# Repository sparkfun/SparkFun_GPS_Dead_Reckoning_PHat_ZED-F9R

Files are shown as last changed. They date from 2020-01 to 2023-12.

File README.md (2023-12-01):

SparkFun GPS-RTK Dead Reckoning pHAT (ZED-F9R) for Raspberry Pi
========================================

SparkFun GPS-RTK Dead Reckoning pHAT (ZED-F9R) for Raspberry Pi (https://www.sparkfun.com/products/21305)

[*SparkFun GPS-RTK Dead Reckoning pHAT (ZED-F9R) for Raspberry Pi (GPS-21305)*](https://www.sparkfun.com/products/21305)

The SparkFun ZED-F9R GPS pHAT is a high precision, sensor fusion GPS board with equally impressive configuration options and takes advantage of u-blox's Automotive Dead Reckoning (ADR) technology. The ZED-F9R module provides a highly accurate and continuous position by fusing a 3D IMU sensor, wheel ticks, a vehicle dynamics model, correction data, and GNSS measurements.

The ZED-F9R module is an 184-channel u-blox F9 engine GNSS receiver, meaning it can receive signals from the GPS, GLONASS, Galileo, and BeiDou constellations with ~0.01-meter accuracy! That's right, such accuracy can be achieved with an RTK navigation solution when used with a correction source. Note that the ZED-F9R can only operate as a rover, so you will need to connect to a base station. The module supports the concurrent reception of four GNSS systems. The combination of GNSS and integrated 3D sensor measurements on the ZED-F9R provides accurate, real-time positioning rates of up to 30Hz.

This pHAT maximizes position accuracy in dense cities or covered areas compared to other GPS modules. Even under poor signal conditions, continuous positioning is provided in urban environments and available during complete signal loss (e.g., short tunnels and parking garages). The ZED-F9R is the ultimate solution for autonomous robotic applications that require accurate positioning under challenging conditions.

This u-blox receiver supports a few serial protocols. By default, we used the Raspberry Pi's serial UART to communicate with the module. With pre-soldered headers, no soldering is required to stack the pHAT on a Raspberry Pi, NVIDIA Jetson Nano, Google Coral, or any single-board computer with the 2x20 form factor. We have also broken out a few 0.1"-spaced pins from the u-blox receiver. A Qwiic connector is also added if you need to connect a Qwiic-enabled device.

U-blox-based GPS products are configurable using the popular but dense Windows program u-center. Many different functions can be configured on the ZED-F9R: baud rates, update rates, geofencing, spoofing detection, external interrupts, SBAS/D-GPS, etc.

The SparkFun ZED-F9R GPS pHAT also has an onboard rechargeable battery that provides power to the RTC on the ZED-F9R. This reduces the time-to-first fix from a cold start (~24s) to a hot start (~2s). The battery will maintain RTC and GNSS orbit data without being connected to power for plenty of time.

Repository Contents
-------------------

* **/Documentation** - Data sheets, additional product information
* **/Hardware** - Eagle design files (.brd, .sch)
* **/Production** - Production panel files (.brd)

Documentation
--------------
* **[Library](https://github.com/sparkfun/Qwiic_Ublox_Gps_Py)** - Python library for the ZED-F9R.
* **[Hookup Guide](https://learn.sparkfun.com/tutorials/1172)** - Basic hookup guide for the ZED-F9R.

Product Versions
----------------
* [GPS-21305](https://www.sparkfun.com/products/21305)
* [GPS-16475](https://www.sparkfun.com/products/16475)

Version History
---------------
* [v1.1](https://github.com/sparkfun/SparkFun_GPS_Dead_Reckoning_PHat_ZED-F9R/releases/tag/v1.1)
* [v1.0](https://github.com/sparkfun/SparkFun_GPS_Dead_Reckoning_PHat_ZED-F9R/releases/tag/v1.0) - Initial Release

License Information
-------------------

This product is _**open source**_! 

Please review the LICENSE.md file for license information. 

If you have any questions or concerns on licensing, please contact technical support on our [SparkFun forums](https://forum.sparkfun.com/viewforum.php?f=152).

Distributed as-is; no warranty is given.

- Your friends at SparkFun.

_<COLLABORATION CREDIT>_

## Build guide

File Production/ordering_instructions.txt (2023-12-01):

panel size, 145x137mm
PCB thickness, 1.6mm
number of layers, 2
soldermask color, Red
silkscreen color, White
oz copper, 1oz
finish, HASL lead free
stencils, top
pcs per panel, 4
min trace width, 0.2032mm / 0.0080in
min drill size, 0.3048mm / 0.0120in

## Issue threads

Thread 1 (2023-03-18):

Where can I find the pinout?

clahil-linum, 2023-03-18:
### Subject of the issue

I try to figure out which pins of the ZED-F9R are connected to which pins of the Raspberry pHAT? I searched the Wiki, try to find something with Google but nothing comes up. I'm especially interessted in the geofence pin.

The only information I found is that the pHat uses the UART from this video: https://www.youtube.com/watch?v=ITBoPNNsycY

bboyho, 2023-12-01:
Hi!

I just noticed this question when updating the GitHub repo. The YouTube video is just the SparkFun product showcase.

For more information, you will want to check the product page or [tutorial](https://learn.sparkfun.com/tutorials/sparkfun-gps-rtk-dead-reckoning-zed-f9r-hookup-guide/hardware-overview-phat). The [pHAT's Eagle design files](https://learn.sparkfun.com/tutorials/sparkfun-gps-rtk-dead-reckoning-zed-f9r-hookup-guide/resources-and-going-further) will show what is connected to the Raspberry Pi's 2x20 GPIO pins. Of course, the schematic will be easier to see but you can highlight the board's traces with the board file.

If you are still wondering, the Geofence pin from the ZED-F9R connects to an LED and it will turn on when the module is configured for geofencing. Looking at the Python Package, it doesn't look like there is an example like the Arduino Library. I haven't tried this feature yet, but you will probably want to configure the module with the u-blox software and then manually wire the pin to a Pi's GPIO before being able to read when the geofence net is high or low.

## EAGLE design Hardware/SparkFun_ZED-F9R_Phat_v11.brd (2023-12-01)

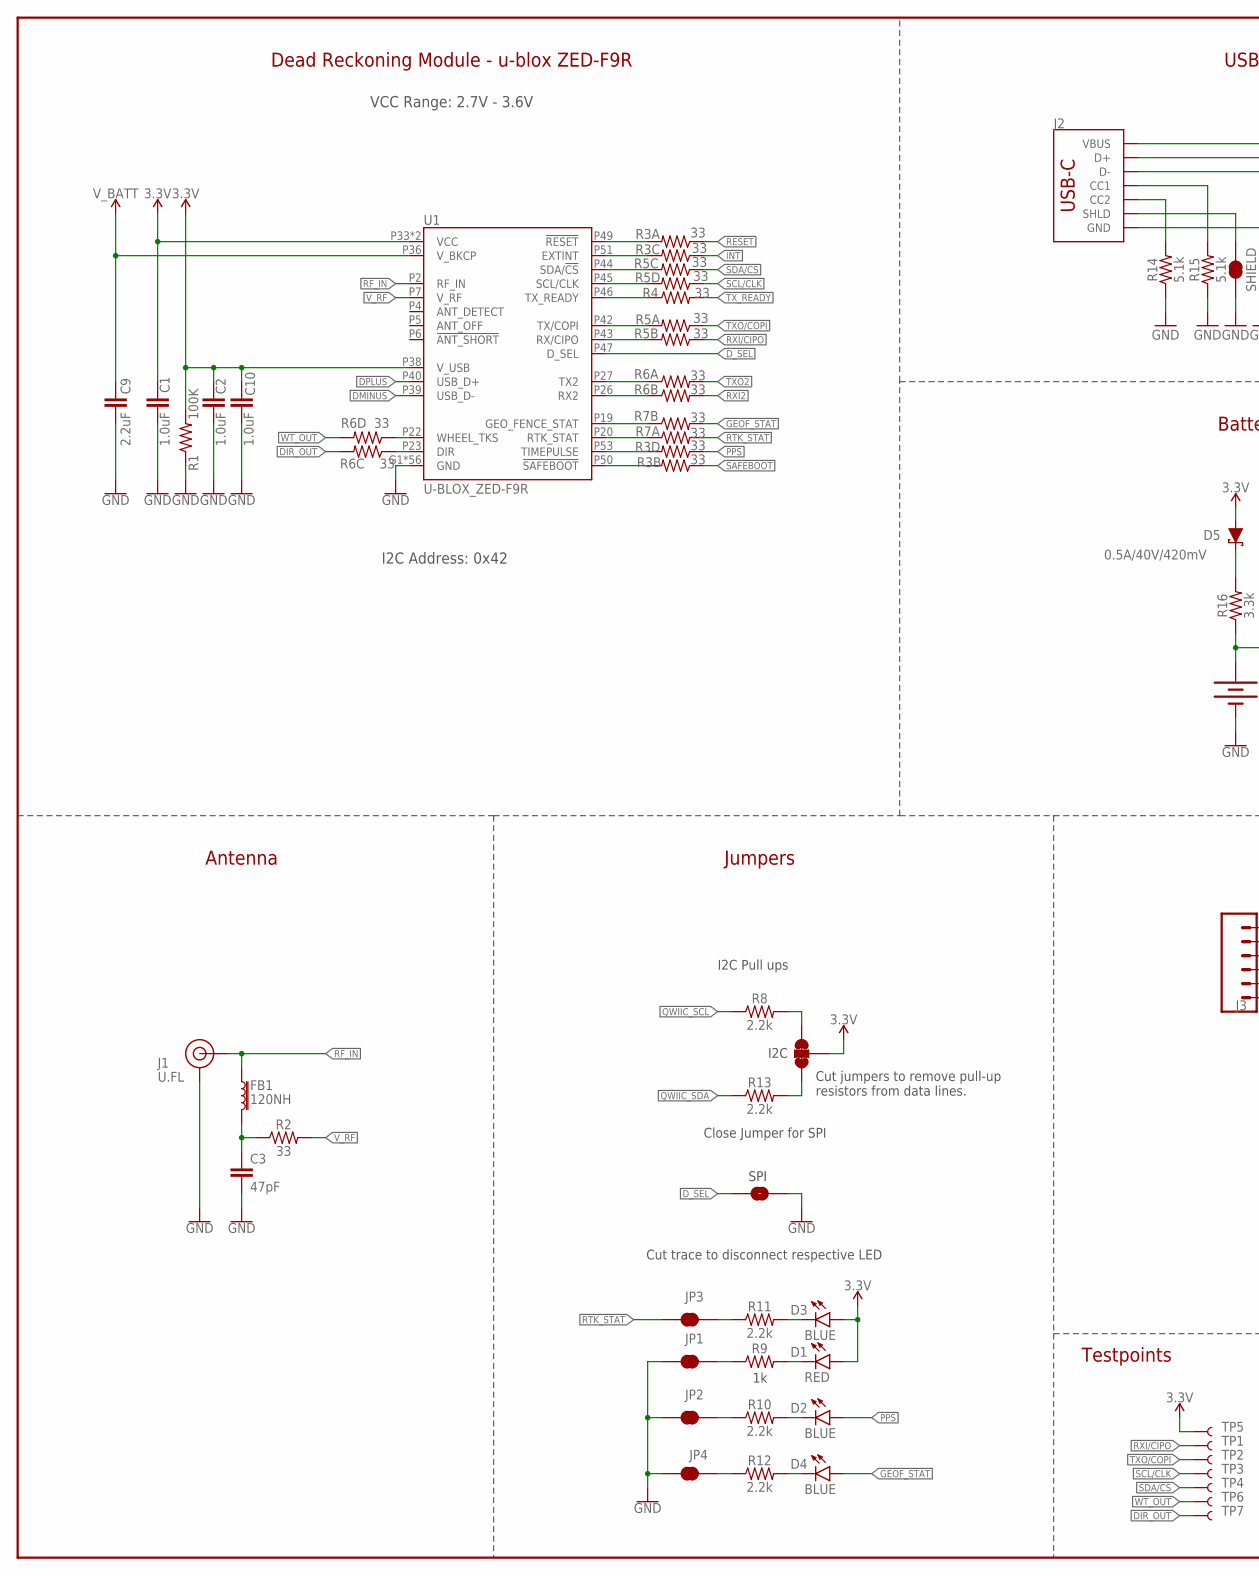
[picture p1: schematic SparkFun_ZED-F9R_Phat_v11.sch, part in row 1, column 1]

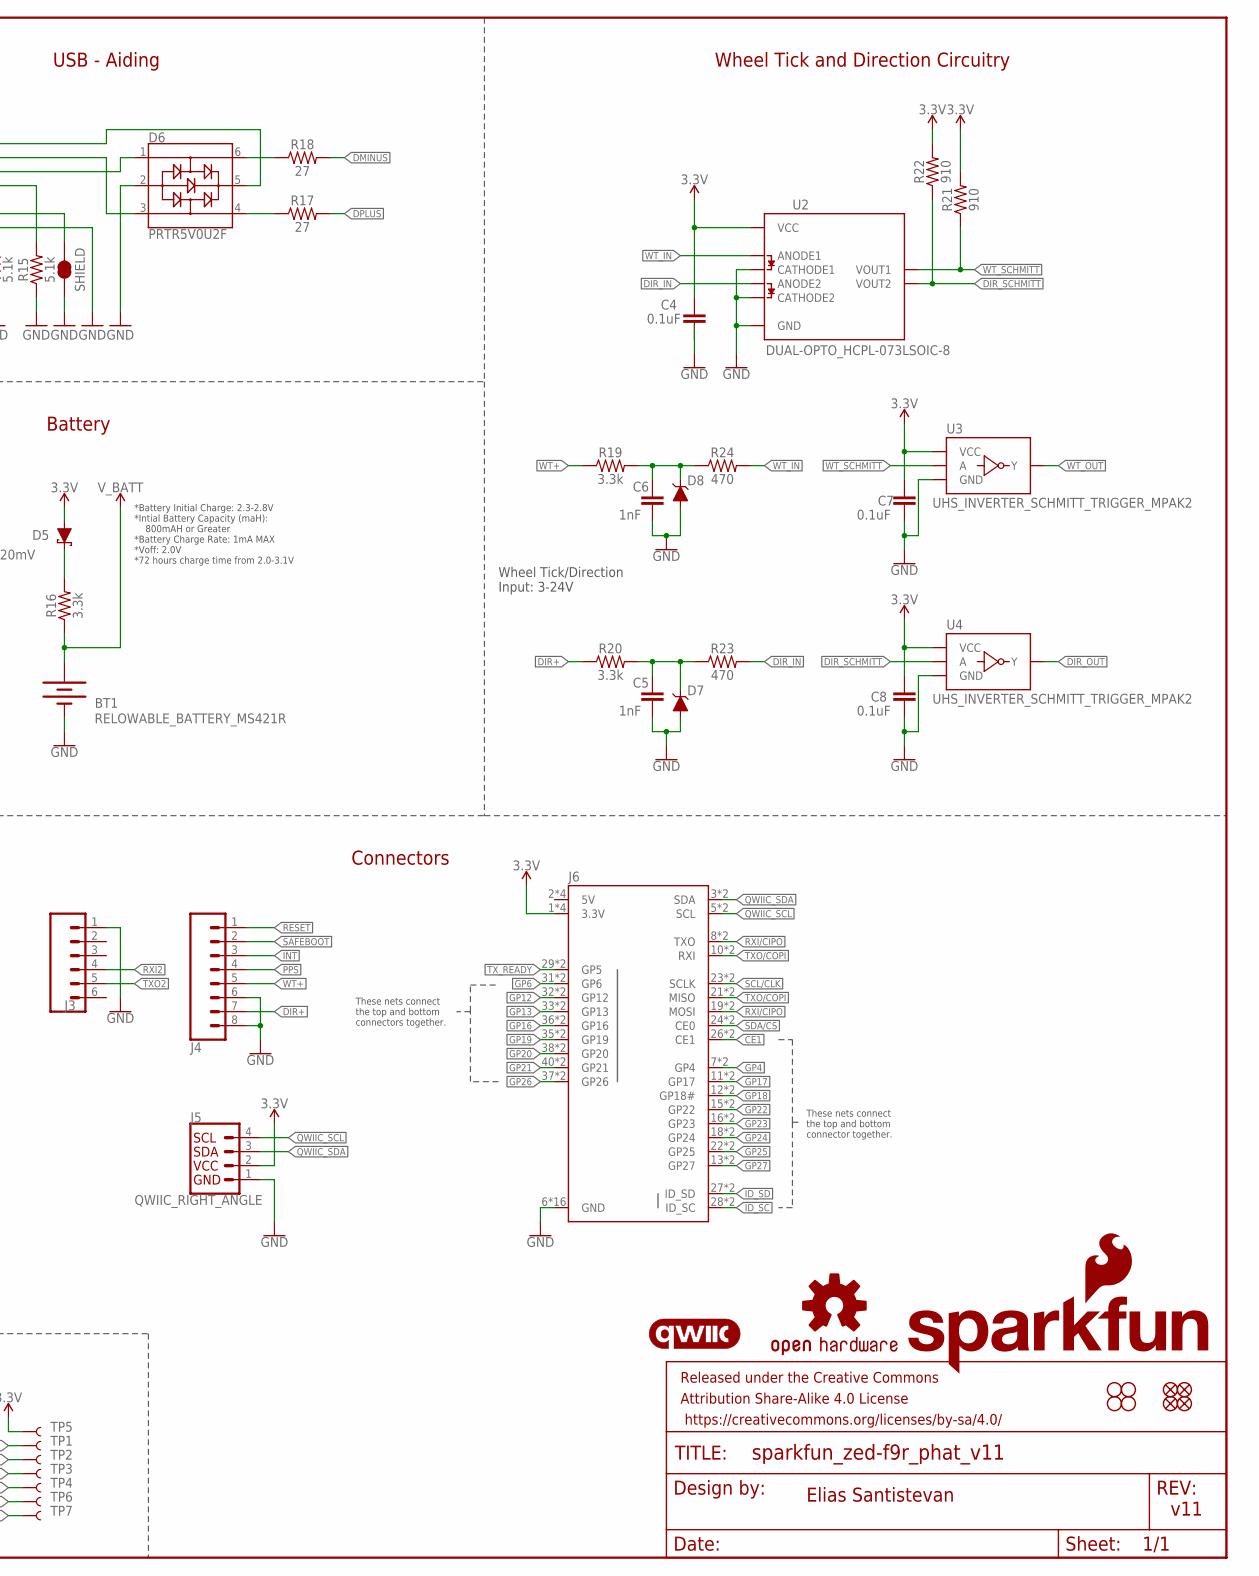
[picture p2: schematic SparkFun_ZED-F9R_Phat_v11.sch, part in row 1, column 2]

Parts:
BT1: RELOWABLE_BATTERY_MS421R; MS421R_IV03E
C1, C2, C10: 1.0uF; 0402
C3: 47pF; 0402
C4, C7, C8: 0.1uF; 0402
C5, C6: 1nF; 0402
C9: 2.2uF; 0402-TIGHT
D1: RED; LED-0603
D2, D3, D4: BLUE; LED-0603
D5: 0.5A/40V/420mV; SOD-323
D6: PRTR5V0U2F; SOT886
D7, D8: 15V; SOT23-3
FB1: 120NH; 0402_MURATA
FD1, FD2, FD3, FD4: FIDUCIALUFIDUCIAL; FIDUCIAL-MICRO
FRAME1: FRAME-LEDGER; CREATIVE_COMMONS
H1, H2, H3, H4: STAND-OFFTIGHT; STAND-OFF-TIGHT
J1: U.FL
J2: USB_C_2-LAYER_PADS; USB-C-16P-2LAYER-PADS
J3: CONN_06NO_SILK_NO_POP; 1X06_NO_SILK
J4: CONN_08NO_SILK_FEMALE_PTH; 1X08_NO_SILK
J5: QWIIC_RIGHT_ANGLE; JST04_1MM_RA
J6: RASPBERRYPI-40-PIN-GPIO_SMD_STACK_NOHOLES_NOREF; RASPBERRY_PI_HAT_40_PIN_SMD_STACKABLE_NOHOLES_NOREF
JP1, JP2, JP3, JP4: JUMPER-SMT_2_NC_TRACE_SILK; SMT-JUMPER_2_NC_TRACE_SILK
JP5: JUMPER-SMT_2_NO_SILK; SMT-JUMPER_2_NO_SILK
JP6: JUMPER-SMT_3_2-NC_TRACE_SILK; SMT-JUMPER_3_2-NC_TRACE_SILK
LOGO1: QWIIC_LOGO_5MM; QWIIC_5MM
LOGO2: OSHW-LOGOM; OSHW-LOGO-M
LOGO3: SFE_LOGO_NAME_FLAME.2_INCH; SFE_LOGO_NAME_FLAME_.2
R1: 100K; 0402
R2, R4: 33; 0603
R3, R5, R6, R7: 33; 1206_RA
R8, R10, R11, R12, R13: 2.2k; 0603
R9: 1k; 0603
R14, R15: 5.1k; 0402
R16, R19, R20: 3.3k; 0603
R17, R18: 27; 0603
R21, R22: 910; 0603
R23, R24: 470; 0603
SHIELD: JUMPER-SMT_2_NC_TRACE_SILK; SMT-JUMPER_2_NC_TRACE_SILK
TP1, TP2, TP3, TP4, TP5, TP6, TP7: TEST-POINT3X4; PAD.03X.04
U1: U-BLOX_ZED-F9R; UBLOX_ZED_F9R
U2: DUAL-OPTO_HCPL-073LSOIC-8; SO08
U3, U4: UHS_INVERTER_SCHMITT_TRIGGER_MPAK2; SIP6_MICROPAK2

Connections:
3.3V: C1.1, C2.1, C4.1, C7.1, C8.1, C10.1, D1.A, D3.A, D5.A, J5.2, J6.1 (3.3V), J6.1B (3.3V), J6.17 (3.3V), J6.17B (3.3V), JP6.2, R1.2, R21.2, R22.2, TP5.P$1, U1.P33 (VCC), U1.P34 (VCC), U1.P38 (V_USB), U2.8 (VCC), U3.P6 (VCC), U4.P6 (VCC)
5V: J6.2 (5V), J6.2B (5V), J6.4 (5V), J6.4B (5V)
!RESET: J4.1, R3.P1 (1)
!SAFEBOOT: J4.2, R3.P2 (1)
CE1: J6.26 (CE1), J6.26B (CE1)
DIR+: J4.7, R20.1
DIR_IN: R23.2, U2.4 (ANODE2)
DIR_OUT: R6.P6 (2), TP7.P$1, U4.P4 (Y)
DIR_SCHMITT: R22.1, U2.6 (VOUT2), U4.P2 (A)
DMINUS: R18.2, U1.P39 (USB_D-)
DPLUS: R17.2, U1.P40 (USB_D+)
D_SEL: JP5.1, U1.P47 (D_SEL)
GEOF_STAT: D4.A, R7.P7 (2)
GND: BT1.-, C1.2, C2.2, C3.2, C4.2, C5.2, C6.2, C7.2, C8.2, C9.2, C10.2, D6.2, D7.1 (A), D8.1 (A), J1.1 (GND), J1.2 (GND), J2.GND, J2.GND2 (GND), J3.1, J4.6, J4.8, J5.1, J6.6 (GND), J6.6B (GND), J6.9 (GND), J6.9B (GND), J6.14 (GND), J6.14B (GND), J6.20 (GND), J6.20B (GND), J6.25 (GND), J6.25B (GND), J6.30 (GND), J6.30B (GND), J6.34 (GND), J6.34B (GND), J6.39 (GND), J6.39B (GND), JP1.1, JP2.1, JP4.1, JP5.2, R1.1, R14.1, R15.1, SHIELD.1, U1.G1 (GND), U1.G2 (GND), U1.G3 (GND), U1.G4 (GND), U1.G5 (GND), U1.G6 (GND), U1.G7 (GND), U1.G8 (GND), U1.G9 (GND), U1.G10 (GND), U1.G11 (GND), U1.G12 (GND), U1.G13 (GND), U1.G14 (GND), U1.G15 (GND), U1.G16 (GND), U1.G17 (GND), U1.G18 (GND), U1.G19 (GND), U1.G20 (GND), U1.G21 (GND), U1.G22 (GND), U1.G23 (GND), U1.G24 (GND), U1.G25 (GND), U1.G26 (GND), U1.G27 (GND), U1.G28 (GND), U1.G29 (GND), U1.G30 (GND), U1.G31 (GND), U1.G32 (GND), U1.G33 (GND), U1.G34 (GND), U1.G35 (GND), U1.G36 (GND), U1.G37 (GND), U1.G38 (GND), U1.G39 (GND), U1.G40 (GND), U1.G41 (GND), U1.G42 (GND), U1.G43 (GND), U1.G44 (GND), U1.G45 (GND), U1.G46 (GND), U1.G47 (GND), U1.G48 (GND), U1.P1 (GND), U1.P3 (GND), U1.P12 (GND), U1.P14 (GND), U1.P32 (GND), U1.P37 (GND), U1.P41 (GND), U1.P48 (GND), U2.2 (CATHODE1), U2.3 (CATHODE2), U2.5 (GND), U3.P3 (GND), U4.P3 (GND)
GP4: J6.7 (GP4), J6.7B (GP4)
GP6: J6.31 (GP6), J6.31B (GP6)
GP12: J6.32 (GP12), J6.32B (GP12)
GP13: J6.33 (GP13), J6.33B (GP13)
GP16: J6.36 (GP16), J6.36B (GP16)
GP17: J6.11 (GP17), J6.11B (GP17)
GP18: J6.12 (GP18#), J6.12B (GP18#)
GP19: J6.35 (GP19), J6.35B (GP19)
GP20: J6.38 (GP20), J6.38B (GP20)
GP21: J6.40 (GP21), J6.40B (GP21)
GP22: J6.15 (GP22), J6.15B (GP22)
GP23: J6.16 (GP23), J6.16B (GP23)
GP24: J6.18 (GP24), J6.18B (GP24)
GP25: J6.22 (GP25), J6.22B (GP25)
GP26: J6.37 (GP26), J6.37B (GP26)
GP27: J6.13 (GP27), J6.13B (GP27)
ID_SC: J6.28 (ID_SC), J6.28B (ID_SC)
ID_SD: J6.27 (ID_SD), J6.27B (ID_SD)
INT: J4.3, R3.P3 (1)
unnamed: JP6.1, R13.2
unnamed: D5.C, R16.2
unnamed: JP6.3, R8.2
unnamed: D1.C, R9.2
unnamed: C3.1, FB1.P2 (2), R2.1
unnamed: D6.6, R18.1
unnamed: D6.4, R17.1
unnamed: JP1.2, R9.1
unnamed: D6.3, J2.A6 (D+), J2.B6 (D+)
unnamed: D6.5, J2.VBUS1 (VBUS), J2.VBUS2 (VBUS)
unnamed: D6.1, J2.A7 (D-), J2.B7 (D-)
unnamed: J2.B5 (CC2), R14.2
unnamed: R3.P8 (2), U1.P49 (!RESET!)
unnamed: R3.P6 (2), U1.P51 (EXTINT)
unnamed: R5.P6 (2), U1.P44 (SDA/!CS!)
unnamed: JP4.2, R12.1
unnamed: D4.C, R12.2
unnamed: J2.A5 (CC1), R15.2
unnamed: R5.P5 (2), U1.P45 (SCL/CLK)
unnamed: R4.1, U1.P46 (TX_READY)
unnamed: R5.P8 (2), U1.P42 (TX/COPI)
unnamed: JP3.2, R11.1
unnamed: JP2.2, R10.1
unnamed: D2.C, R10.2
unnamed: D3.C, R11.2
unnamed: R5.P7 (2), U1.P43 (RX/CIPO)
unnamed: C6.1, D8.3 (C), R19.2, R24.1
unnamed: R7.P2 (1), U1.P19 (GEO_FENCE_STAT)
unnamed: R7.P1 (1), U1.P20 (RTK_STAT)
unnamed: R3.P5 (2), U1.P53 (TIMEPULSE)
unnamed: R3.P7 (2), U1.P50 (!SAFEBOOT!)
unnamed: R6.P1 (1), U1.P27 (TX2)
unnamed: R6.P2 (1), U1.P26 (RX2)
unnamed: R6.P4 (1), U1.P22 (WHEEL_TKS)
unnamed: R6.P3 (1), U1.P23 (DIR)
unnamed: C5.1, D7.3 (C), R20.2, R23.1
PPS: D2.A, J4.4, R3.P4 (1)
QWIIC_SCL: J5.4, J6.5 (SCL), J6.5B (SCL), R8.1
QWIIC_SDA: J5.3, J6.3 (SDA), J6.3B (SDA), R13.1
RF_IN: FB1.P1 (1), J1.FEED (SIGNAL), U1.P2 (RF_IN)
RTK_STAT: JP3.1, R7.P8 (2)
RXI2: J3.4, R6.P7 (2)
RXI/CIPO: J6.8 (TXO), J6.8B (TXO), J6.19 (MOSI), J6.19B (MOSI), R5.P2 (1), TP1.P$1
SCL/CLK: J6.23 (SCLK), J6.23B (SCLK), R5.P4 (1), TP3.P$1
SDA/!CS: J6.24 (CE0), J6.24B (CE0), R5.P3 (1), TP4.P$1
SHIELD: J2.SHLD1 (SHLD), J2.SHLD2 (SHLD), J2.SHLD3 (SHLD), J2.SHLD4 (SHLD), SHIELD.2
TXO2: J3.5, R6.P8 (2)
TXO/COPI: J6.10 (RXI), J6.10B (RXI), J6.21 (MISO), J6.21B (MISO), R5.P1 (1), TP2.P$1
TX_READY: J6.29 (GP5), J6.29B (GP5), R4.2
V_BATT: BT1.+, C9.1, R16.1, U1.P36 (V_BKCP)
V_RF: R2.2, U1.P7 (V_RF)
WT+: J4.5, R19.1
WT_IN: R24.2, U2.1 (ANODE1)
WT_OUT: R6.P5 (2), TP6.P$1, U3.P4 (Y)
WT_SCHMITT: R21.1, U2.7 (VOUT1), U3.P2 (A)

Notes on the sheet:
v11
Elias Santistevan
Dead Reckoning Module - u-blox ZED-F9R
Battery
Connectors
Jumpers
Close Jumper for SPI
I2C Pull ups
Cut trace to disconnect respective LED
Antenna
*Battery Initial Charge: 2.3-2.8V *Intial Battery Capacity (maH): 800mAH or Greater *Battery Charge Rate: 1mA MAX *Voff: 2.0V *72 hours charge time from 2.0-3.1V
VCC Range: 2.7V - 3.6V
I2C Address: 0x42
USB - Aiding
Cut jumpers to remove pull-up resistors from data lines.
SPI
I2C
Testpoints
These nets connect the top and bottom connector together.
These nets connect the top and bottom connectors together.
Wheel Tick and Direction Circuitry
Wheel Tick/Direction Input: 3-24V

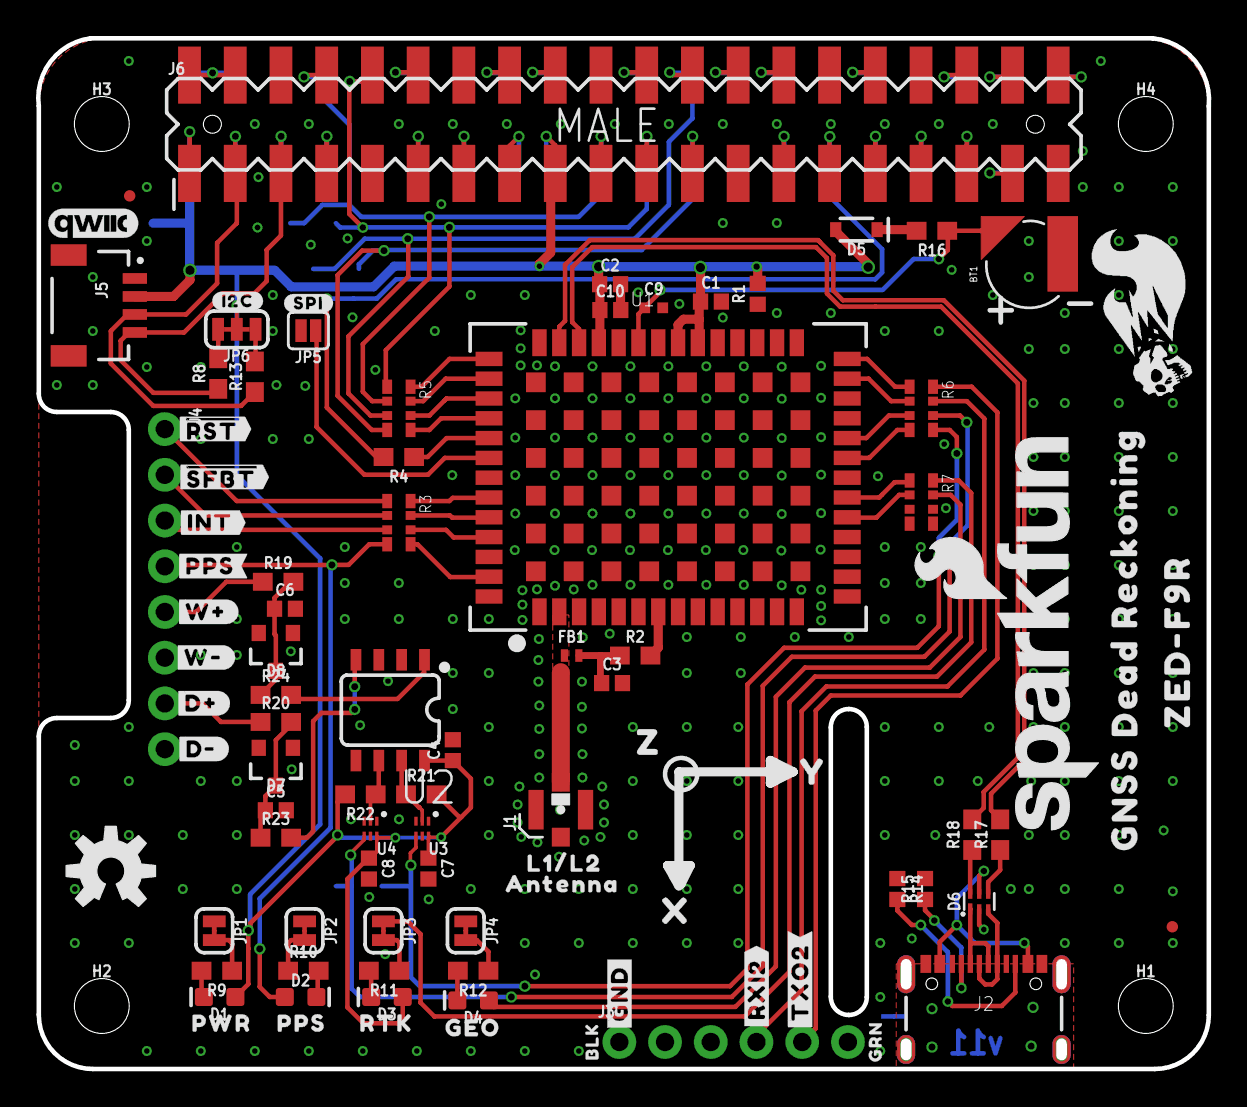
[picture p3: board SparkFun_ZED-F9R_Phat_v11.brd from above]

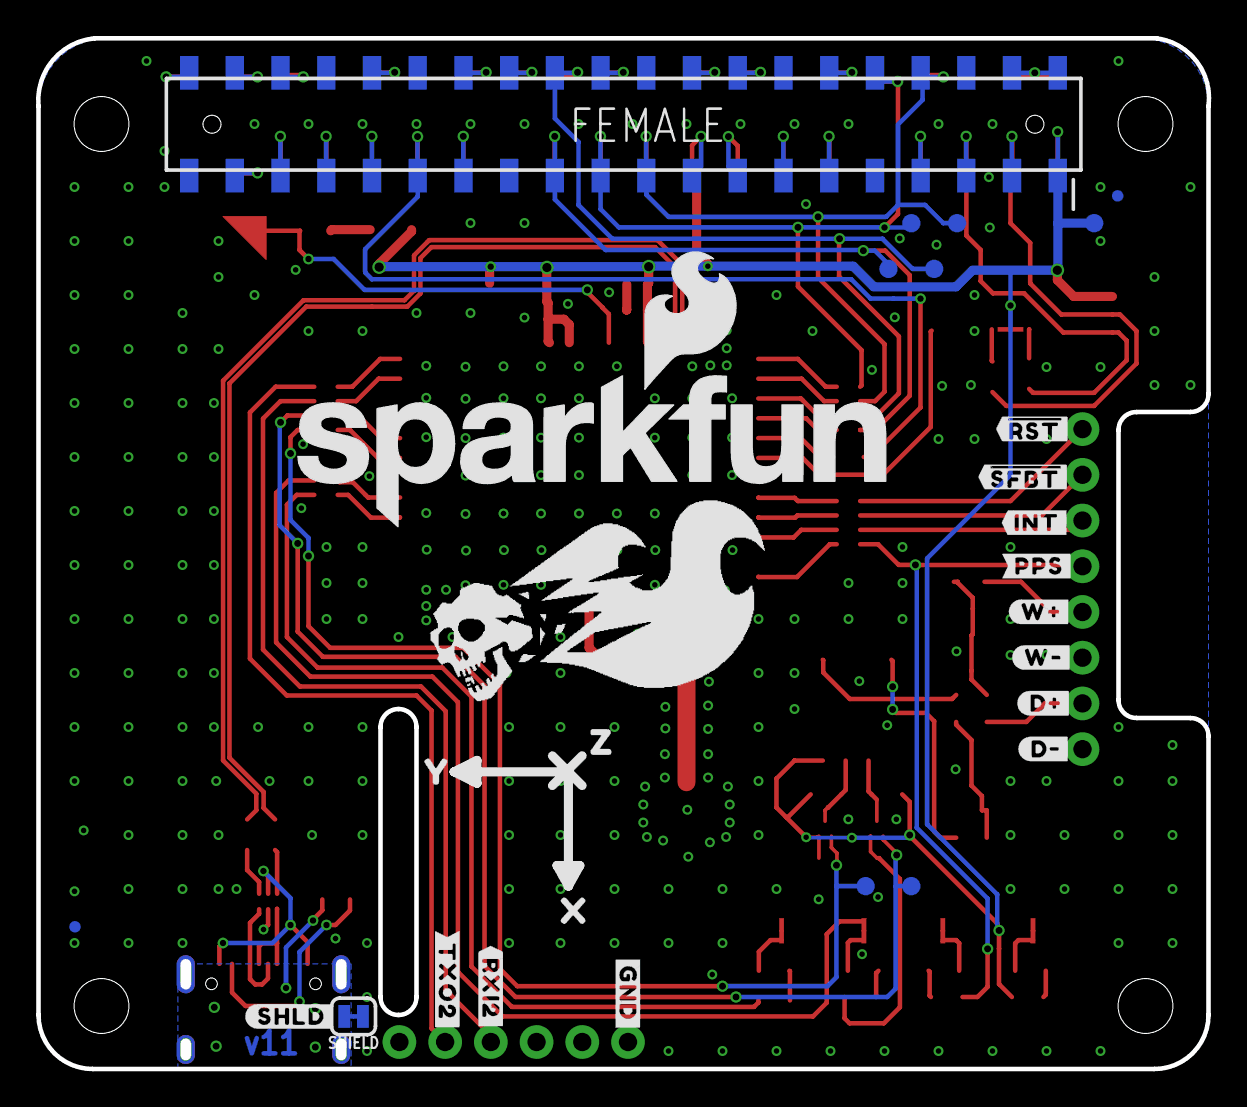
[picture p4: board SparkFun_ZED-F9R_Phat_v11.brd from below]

Board: 2 copper layers, 65.0 x 57.3 mm, 124 parts (27 on the bottom side), 88 nets.

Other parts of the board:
U$1: ##RST##28
U$2: ##SFBT##30
U$3: PPS9
U$4: PWR7
U$5: GEO11
U$6: #RXI2#34
U$7: #INT#1
U$8: #PPS#3
U$9: SFE_LOGO_NAME_FLAME_.3@1
U$10: #TXO2#235
U$11: #W##2253
U$12: #W##2254
U$13: #D##2249
U$14: GNSS_DEAD_RECKONING25
U$15: #D##2250
U$16: ZED#F9R25
U$17: BLK22
U$18, U$19: #GND#20
U$20: #SPI#4
U$21: L1#L26
U$22: #I2C#5
U$23: RTK13
U$24: GRN23
U$25, U$28: Z20
U$26, U$29: Y19
U$27, U$45: X18
U$31, U$36: DEAD#RECKONING#GPS#BOARD#SILK#FINAL#JPG
U$32: ##RST##27
U$33: ##SFBT##29
U$34: #INT#0
U$35: #PPS#2
U$37: #W##2251
U$38: #W##2252
U$39: #D##2247
U$40: #D##2248
U$41: ANTENNA6
U$42: #TXO2#236
U$43: #RXI2#35
U$44: #SHLD#2258

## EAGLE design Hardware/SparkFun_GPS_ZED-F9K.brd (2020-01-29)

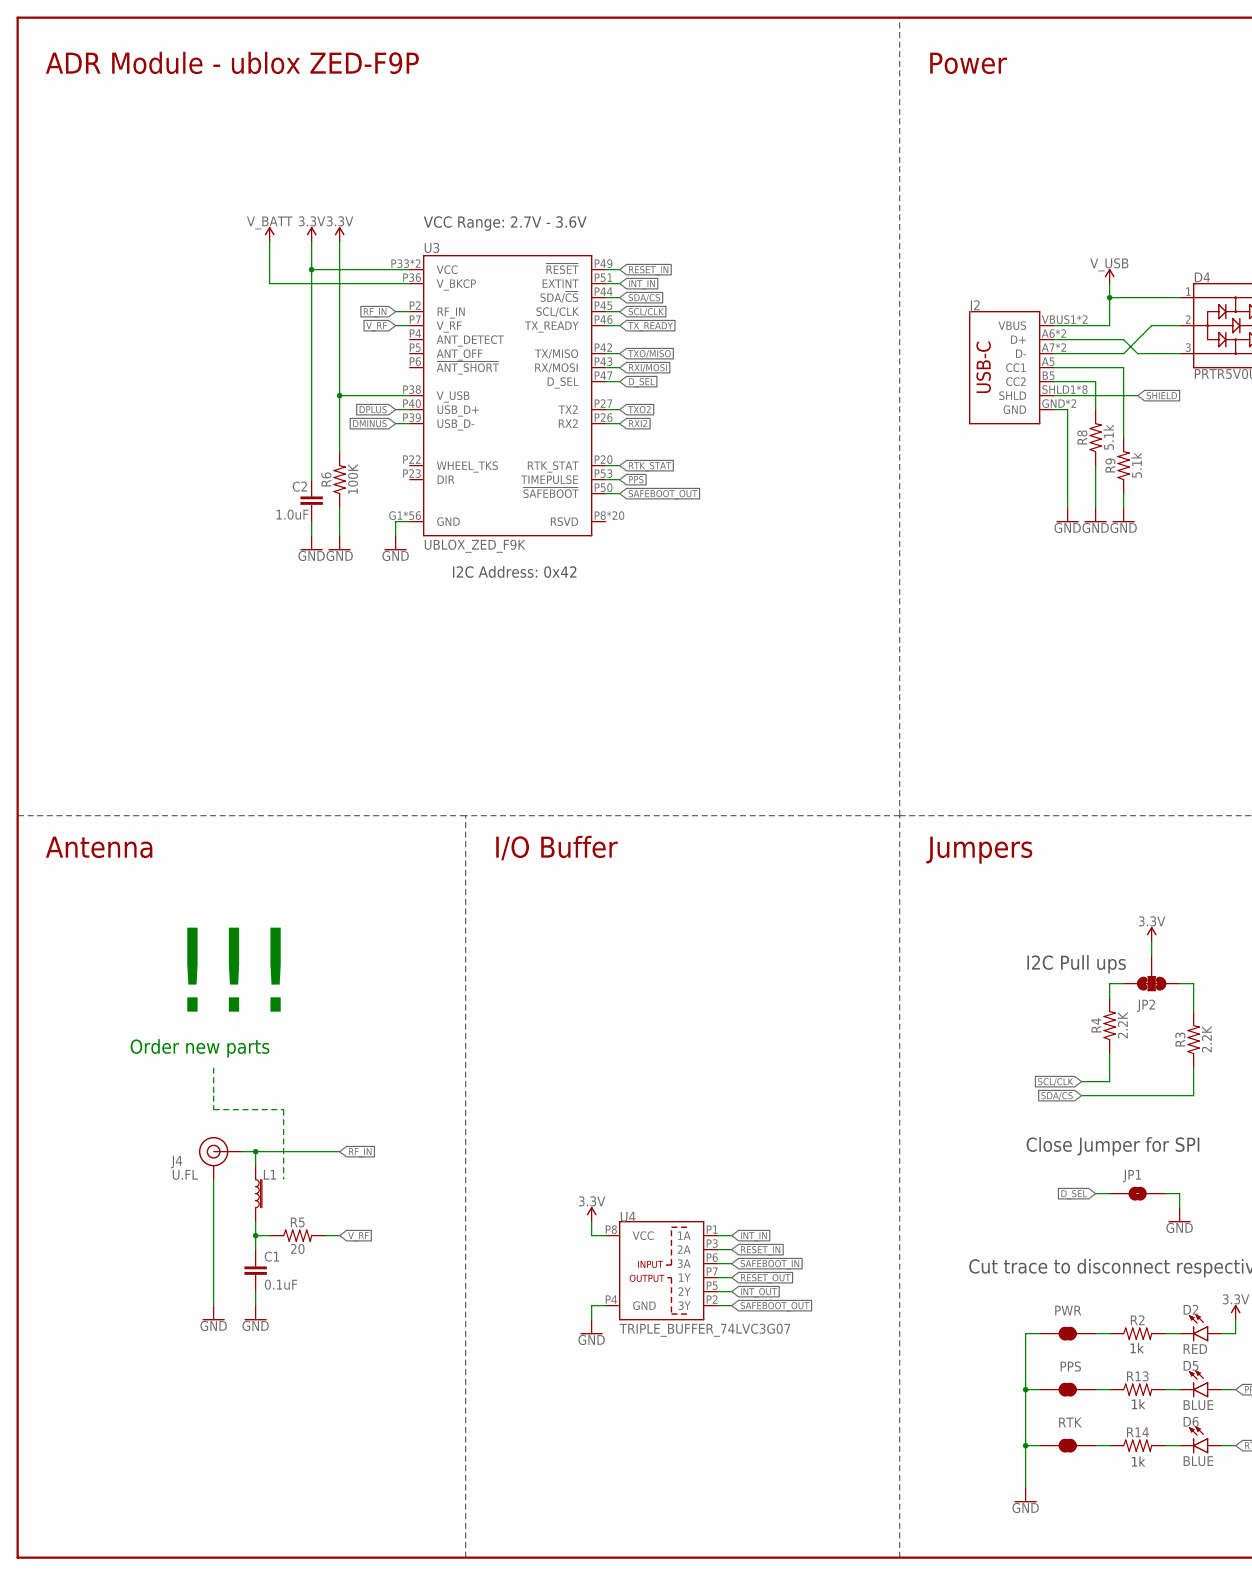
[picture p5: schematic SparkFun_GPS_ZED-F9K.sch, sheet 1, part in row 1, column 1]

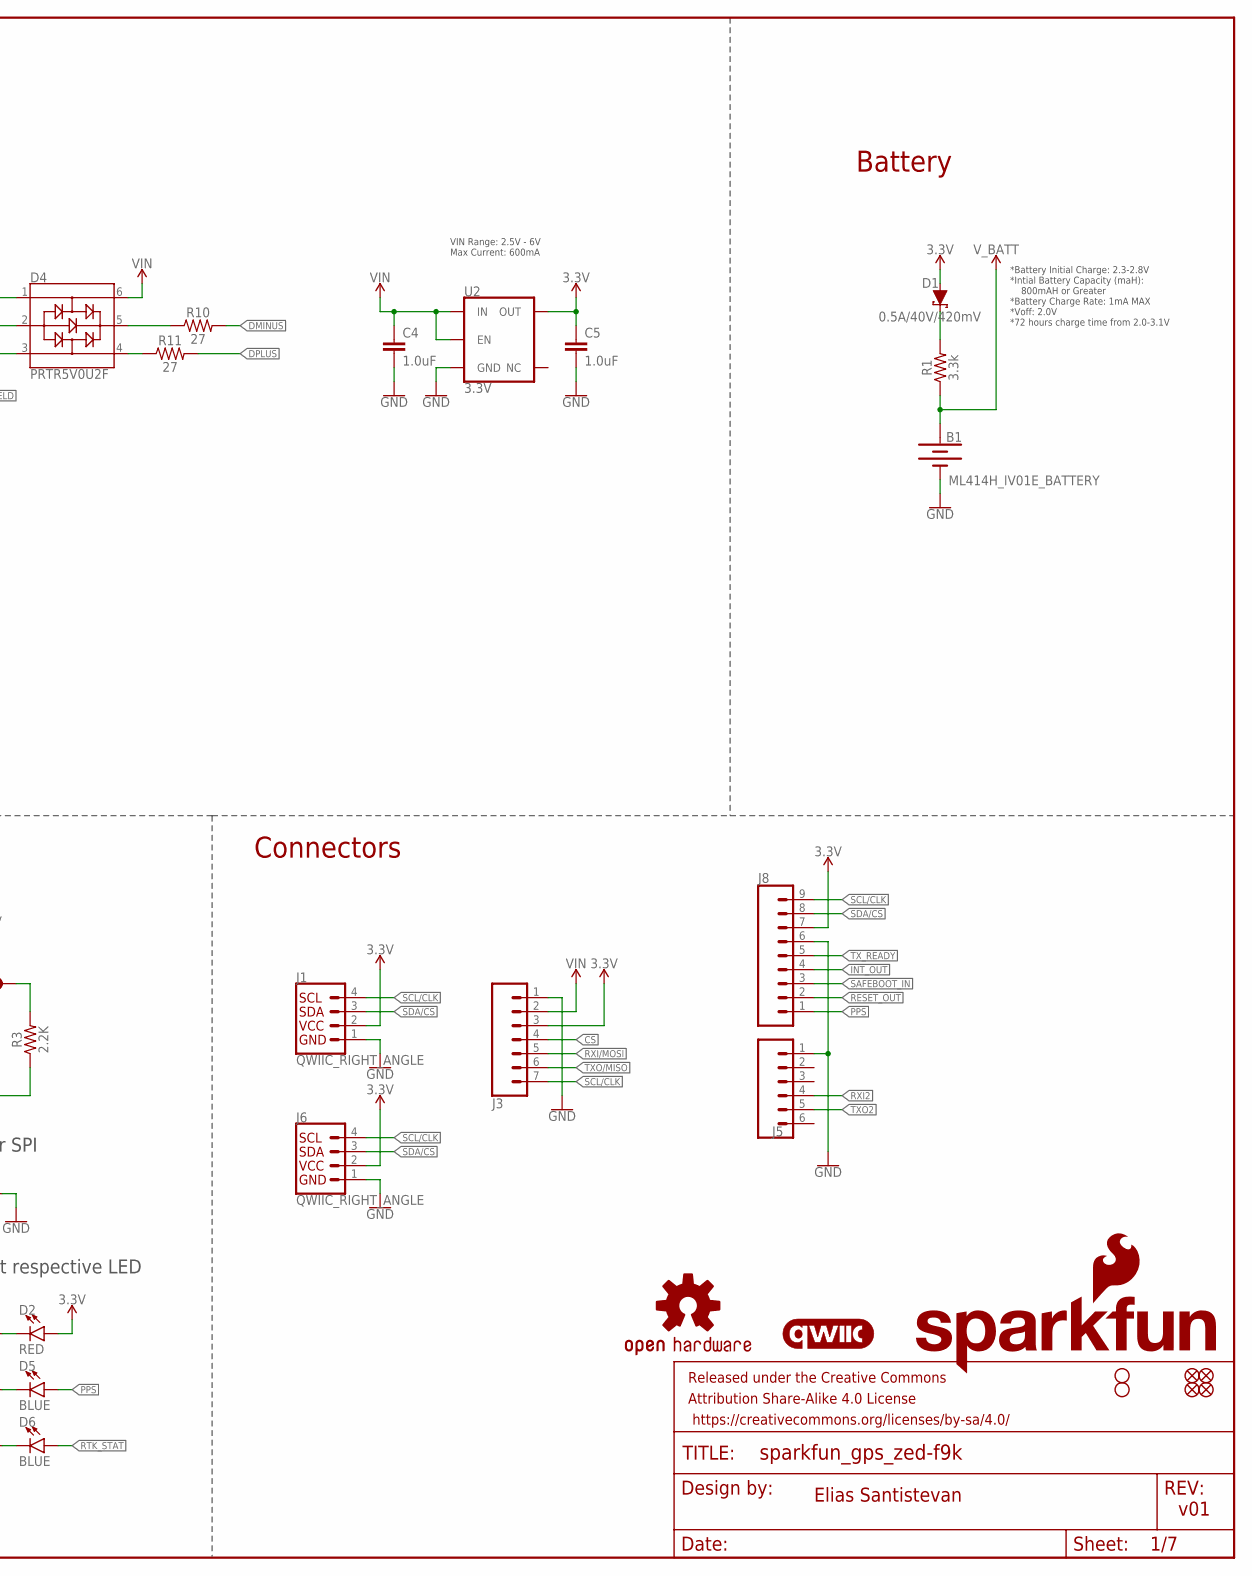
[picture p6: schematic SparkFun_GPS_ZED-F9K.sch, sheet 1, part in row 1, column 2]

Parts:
B1: ML414H_IV01E_BATTERY; ML414H_IV01E
C1: 0.1uF; 0402
C2: 1.0uF; 0402
C4, C5: 1.0uF; 0603
D1: 0.5A/40V/420mV; SOD-323
D2: RED; LED-0603
D4: PRTR5V0U2F; SOT886
D5, D6: BLUE; LED-0603
FD1, FD2, FD3, FD4: FIDUCIALUFIDUCIAL; FIDUCIAL-MICRO
FRAME2: FRAME-LEDGER; CREATIVE_COMMONS
H2, H3: STAND-OFFTIGHT; STAND-OFF-TIGHT
J1, J6: QWIIC_RIGHT_ANGLE; JST04_1MM_RA
J2: USB_C2-LAYER; USB-C-16P
J3: CONN_07NO_SILK; 1X07_NO_SILK
J4: U.FL
J5: CONN_06NO_SILK_NO_POP; 1X06_NO_SILK
J8: CONN_09NO_SILK; 1X09_NO_SILK
JP1: JUMPER-SMT_2_NO_SILK; SMT-JUMPER_2_NO_SILK
JP2: JUMPER-SMT_3_2-NC_TRACE_SILK; SMT-JUMPER_3_2-NC_TRACE_SILK
L1: 3.9NH; 0402
LOGO1: SFE_LOGO_NAME_FLAME.2_INCH; SFE_LOGO_NAME_FLAME_.2
LOGO2: QWIIC_LOGO_4MM; QWIIC_4MM
LOGO3: OSHW-LOGOM; OSHW-LOGO-M
PPS: JUMPER-SMT_2_NC_TRACE_SILK; SMT-JUMPER_2_NC_TRACE_SILK
PWR: JUMPER-SMT_2_NC_TRACE_SILK; SMT-JUMPER_2_NC_TRACE_SILK
R1: 3.3k; 0603
R2, R13, R14: 1KOHM-0402-1/16W-1%; 0402
R3, R4: 2.2K; 0402
R5: 20; 0603
R6: 100K; 0402
R8, R9: 5.1k; 0402
R10, R11: 27; 0603
RTK: JUMPER-SMT_2_NC_TRACE_SILK; SMT-JUMPER_2_NC_TRACE_SILK
U2: 3.3V; SOT23-5
U3: UBLOX_ZED_F9K
U4: TRIPLE_BUFFER_74LVC3G07; SOP_8-PIN

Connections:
3.3V: C2.1, C5.1, D1.A, D2.A, J1.2, J3.3, J6.2, J8.7, JP2.2, R6.2, U2.5 (OUT), U3.P33 (VCC), U3.P34 (VCC), U3.P38 (V_USB), U4.P8 (VCC)
!CS: J3.4
!RESET_IN: U3.P49 (!RESET!), U4.P3 (2A)
!RESET_OUT: J8.2, U4.P7 (1Y)
!SAFEBOOT_IN: J8.3, U4.P6 (3A)
!SAFEBOOT_OUT: U3.P50 (!SAFEBOOT!), U4.P2 (3Y)
DMINUS: R10.2, U3.P39 (USB_D-)
DPLUS: R11.2, U3.P40 (USB_D+)
D_SEL: JP1.1, U3.P47 (D_SEL)
GND: B1.-, C1.2, C2.2, C4.2, C5.2, J1.1, J2.GND, J2.GND2 (GND), J3.1, J4.1 (GND), J4.2 (GND), J5.1, J6.1, J8.6, JP1.2, PPS.1, PWR.1, R6.1, R8.1, R9.1, RTK.1, U2.2 (GND), U3.G1 (GND), U3.G2 (GND), U3.G3 (GND), U3.G4 (GND), U3.G5 (GND), U3.G6 (GND), U3.G7 (GND), U3.G8 (GND), U3.G9 (GND), U3.G10 (GND), U3.G11 (GND), U3.G12 (GND), U3.G13 (GND), U3.G14 (GND), U3.G15 (GND), U3.G16 (GND), U3.G17 (GND), U3.G18 (GND), U3.G19 (GND), U3.G20 (GND), U3.G21 (GND), U3.G22 (GND), U3.G23 (GND), U3.G24 (GND), U3.G25 (GND), U3.G26 (GND), U3.G27 (GND), U3.G28 (GND), U3.G29 (GND), U3.G30 (GND), U3.G31 (GND), U3.G32 (GND), U3.G33 (GND), U3.G34 (GND), U3.G35 (GND), U3.G36 (GND), U3.G37 (GND), U3.G38 (GND), U3.G39 (GND), U3.G40 (GND), U3.G41 (GND), U3.G42 (GND), U3.G43 (GND), U3.G44 (GND), U3.G45 (GND), U3.G46 (GND), U3.G47 (GND), U3.G48 (GND), U3.P1 (GND), U3.P3 (GND), U3.P12 (GND), U3.P14 (GND), U3.P32 (GND), U3.P37 (GND), U3.P41 (GND), U3.P48 (GND), U4.P4 (GND)
INT_IN: U3.P51 (EXTINT), U4.P1 (1A)
INT_OUT: J8.4, U4.P5 (2Y)
unnamed: JP2.1, R3.2
unnamed: D1.C, R1.2
unnamed: JP2.3, R4.2
unnamed: D2.C, R2.2
unnamed: C1.1, L1.2, R5.1
unnamed: D4.3, J2.A6 (D+), J2.B6 (D+)
unnamed: D4.2, J2.A7 (D-), J2.B7 (D-)
unnamed: PWR.2, R2.1
unnamed: J2.B5 (CC2), R8.2
unnamed: J2.A5 (CC1), R9.2
unnamed: D4.5, R10.1
unnamed: D4.4, R11.1
unnamed: R14.1, RTK.2
unnamed: PPS.2, R13.1
unnamed: D5.C, R13.2
unnamed: D6.C, R14.2
PPS: D5.A, J8.1, U3.P53 (TIMEPULSE)
RF_IN: J4.FEED (SIGNAL), L1.1, U3.P2 (RF_IN)
RTK_STAT: D6.A, U3.P20 (RTK_STAT)
RXI2: J5.4, U3.P26 (RX2)
RXI/MOSI: J3.5, U3.P43 (RX/MOSI)
SCL/CLK: J1.4, J3.7, J6.4, J8.9, R4.1, U3.P45 (SCL/CLK)
SDA/!CS: J1.3, J6.3, J8.8, R3.1, U3.P44 (SDA/!CS!)
SHIELD: J2.SHLD1 (SHLD), J2.SHLD2 (SHLD), J2.SHLD3 (SHLD), J2.SHLD4 (SHLD), J2.SHLD5 (SHLD), J2.SHLD6 (SHLD), J2.SHLD7 (SHLD), J2.SHLD8 (SHLD)
TXO2: J5.5, U3.P27 (TX2)
TXO/MISO: J3.6, U3.P42 (TX/MISO)
TX_READY: J8.5, U3.P46 (TX_READY)
VIN: C4.1, D4.6, J3.2, U2.1 (IN), U2.3 (EN)
V_BATT: B1.+, R1.1, U3.P36 (V_BKCP)
V_RF: R5.2, U3.P7 (V_RF)
V_USB: D4.1, J2.VBUS1 (VBUS), J2.VBUS2 (VBUS)

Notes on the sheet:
v01
Elias Santistevan
ADR Module - ublox ZED-F9P
Battery
Connectors
Jumpers
Close Jumper for SPI
I2C Pull ups
Cut trace to disconnect respective LED
Antenna
*Battery Initial Charge: 2.3-2.8V *Intial Battery Capacity (maH): 800mAH or Greater *Battery Charge Rate: 1mA MAX *Voff: 2.0V *72 hours charge time from 2.0-3.1V
Order new parts
!!!
VIN Range: 2.5V - 6V Max Current: 600mA
Power
I/O Buffer
VCC Range: 2.7V - 3.6V
I2C Address: 0x42

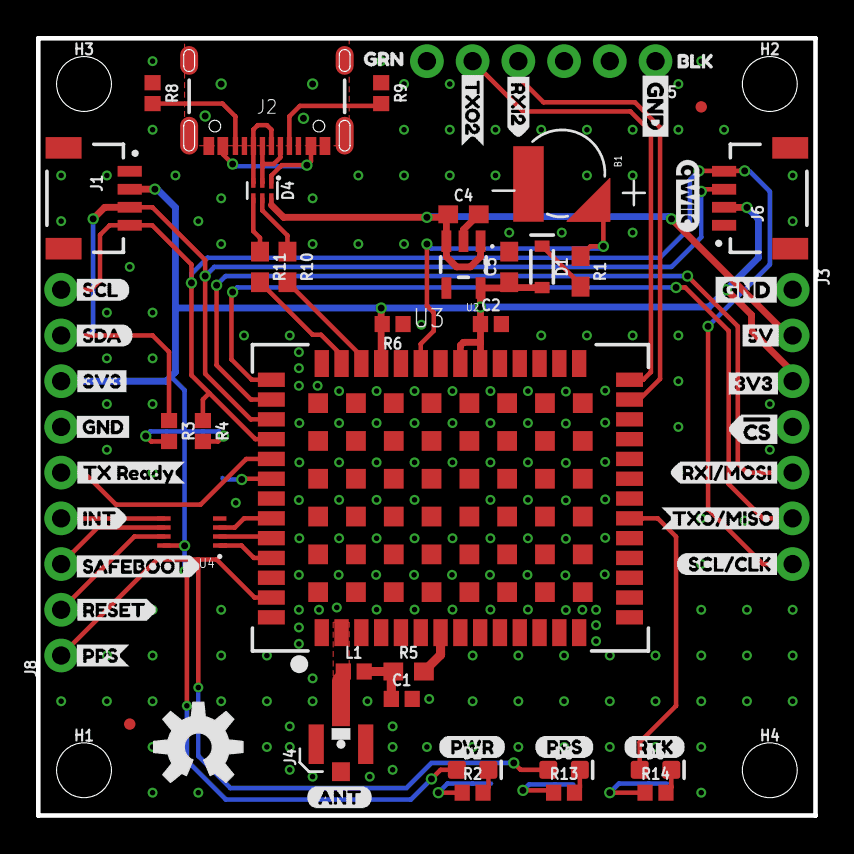
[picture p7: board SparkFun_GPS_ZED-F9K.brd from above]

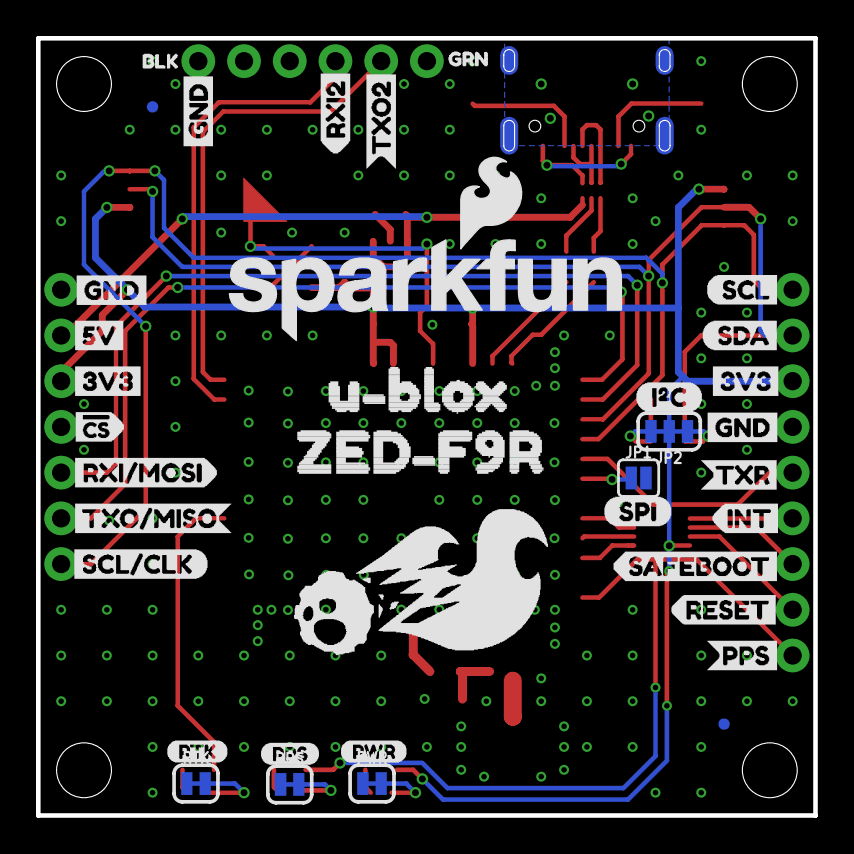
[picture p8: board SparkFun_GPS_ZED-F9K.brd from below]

Board: 2 copper layers, 43.2 x 43.2 mm, 104 parts (37 on the bottom side), 42 nets.

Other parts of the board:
H1, H4: STAND-OFFTIGHT; STAND-OFF-TIGHT
U$1, U$24: INT2
U$2: PPS4
U$3, U$19: 3V32
U$4, U$47: PPS8
U$5, U$48: PWR10
U$6: GND3
U$7: RESET3
U$8, U$22: RTK9
U$9: RXI#MOSI5
U$10: SAFEBOOT1
U$11: SCL0
U$12: SDA1
U$13: SCL#CLK7
U$14: RXI22
U$15: TXO#MISO6
U$16: TX_READY0
U$17, U$20: GND-03
U$18: 5V0
U$21, U$54: BLK2
U$23, U$53: GRN1
U$25, U$36: TXO21
U$26: CS#-<]-04
U$27: PPS1
U$28: RESET4
U$29, U$40: 3V3-04
U$30: RXI#MOSI0
U$31, U$34, U$41: GND-04
U$32: SAFEBOOT3
U$33: 5V
U$35: RXI28
U$37: TXO#MISO1
U$38: SCL#CLK2
U$39: SCL5
U$42: SDA4
U$43: TXR3
U$45: SPI4
U$46: I_SUPER2_C-()-04
U$49: ANT0
U$50: NEO_GPS_BOARD_SILK_FINAL#03#JPG
U$51: ZED#F9R0
U$52: U#BLOX1
U$59: CS#-[>-04

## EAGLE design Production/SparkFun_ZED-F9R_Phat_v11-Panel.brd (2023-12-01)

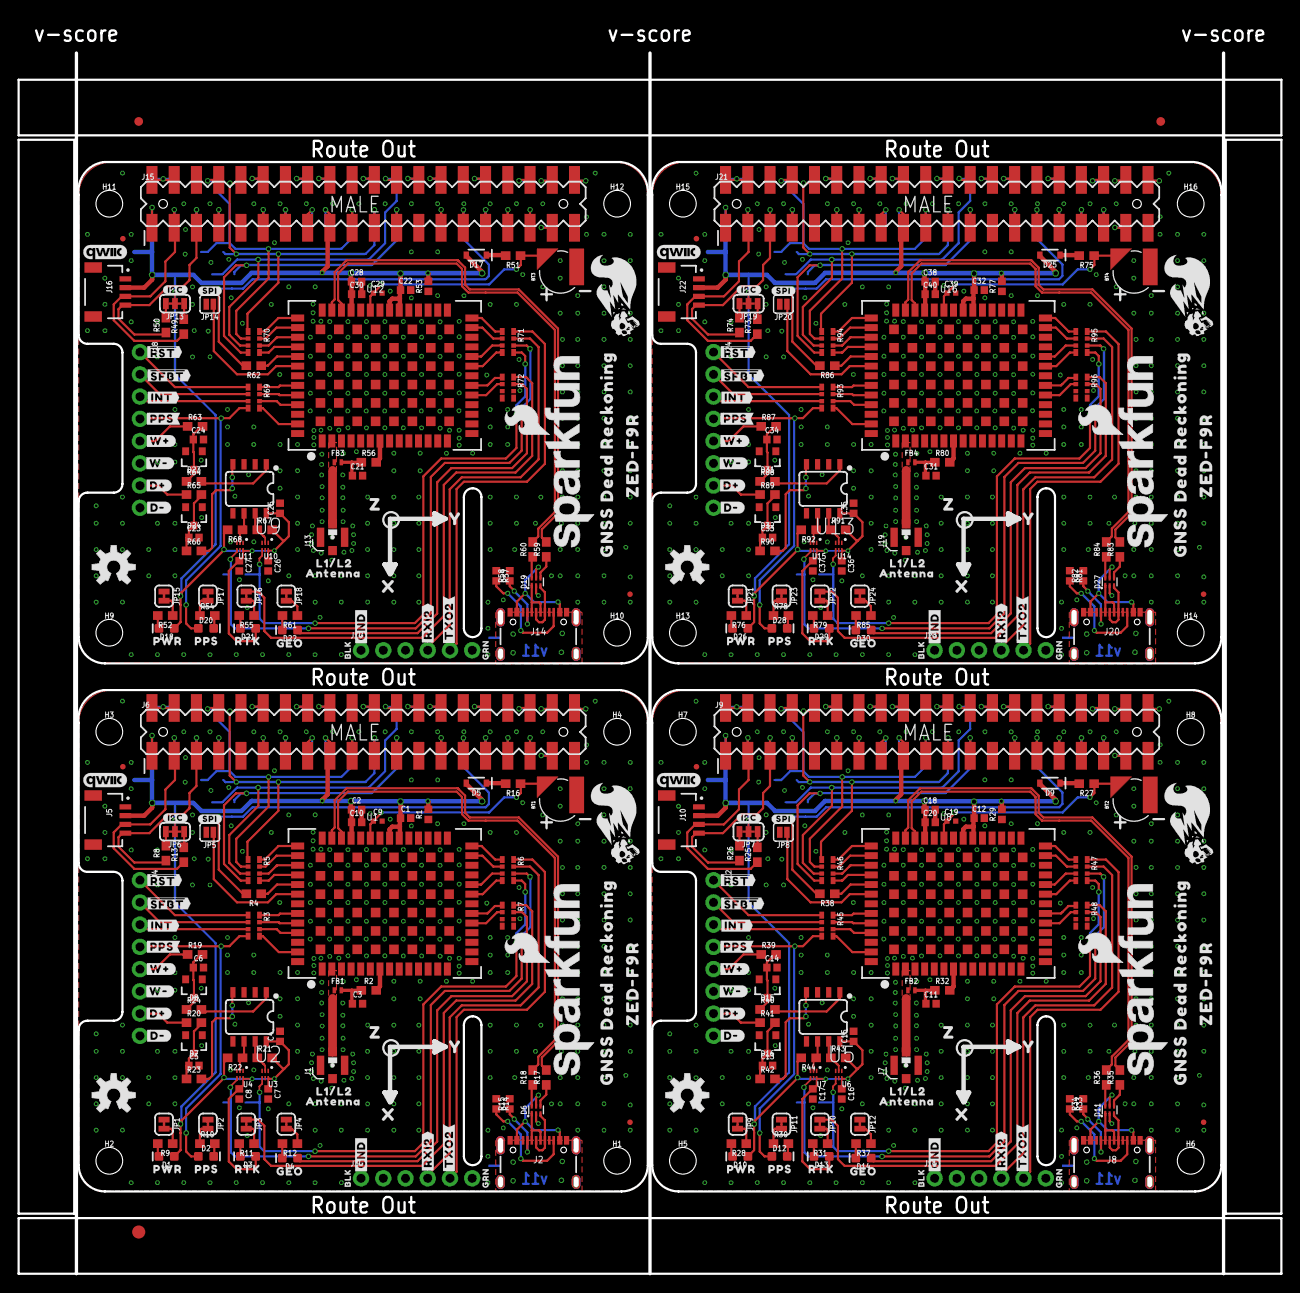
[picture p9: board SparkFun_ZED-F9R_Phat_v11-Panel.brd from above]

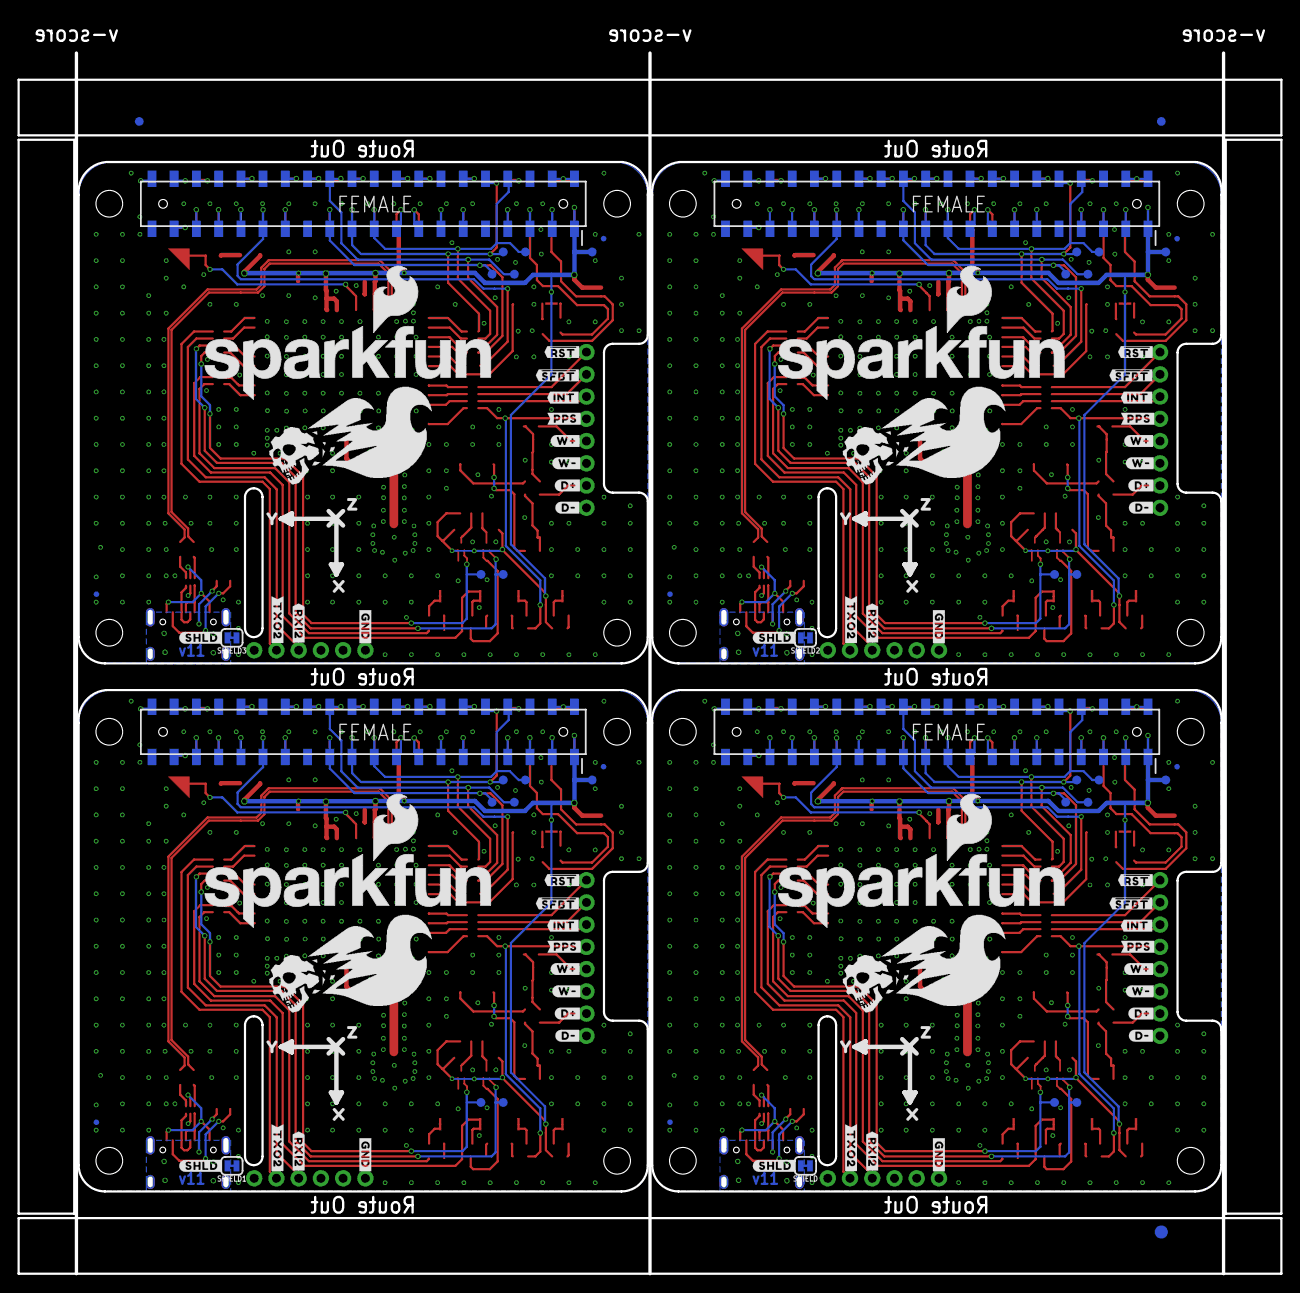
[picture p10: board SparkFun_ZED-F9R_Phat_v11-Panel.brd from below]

Board: 2 copper layers, 144.2 x 139.4 mm, 498 parts (111 on the bottom side), 352 nets.

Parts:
BT1, BT2, BT3, BT4: RELOWABLE_BATTERY_MS421R; MS421R_IV03E
C1, C2, C10, C12, C18, C20, C22, C28, C30, C32, C38, C40: 1.0uF; 0402
C3, C11, C21, C31: 47pF; 0402
C4, C7, C8, C15, C16, C17, C25, C26, C27, C35, C36, C37: 0.1uF; 0402
C5, C6, C13, C14, C23, C24, C33, C34: 1nF; 0402
C9, C19, C29, C39: 2.2uF; 0402-TIGHT
D1, D10, D18, D26: RED; LED-0603
D2, D3, D4, D12, D13, D14, D20, D21, D22, D28, D29, D30: BLUE; LED-0603
D5, D9, D17, D25: 0.5A/40V/420mV; SOD-323
D6, D11, D19, D27: PRTR5V0U2F; SOT886
D7, D8, D15, D16, D23, D24, D31, D32: 15V; SOT23-3
E$1, E$2, E$3, E$4: FIDUCIAL-1X2
E$5, E$6: FIDUCIAL-1.5X3
FB1, FB2, FB3, FB4: 120NH; 0402_MURATA
FD1, FD2, FD3, FD4, FD5, FD6, FD7, FD8, FD9, FD10, FD11, FD12, FD13, FD14, FD15, FD16: FIDUCIALUFIDUCIAL; FIDUCIAL-MICRO
H1, H2, H3, H4, H5, H6, H7, H8, H9, H10, H11, H12, H13, H14, H15, H16: STAND-OFFTIGHT; STAND-OFF-TIGHT
J1, J7, J13, J19: U.FL
J2, J8, J14, J20: USB-C-16P-2LAYER-PADS
J3, J11, J17, J23: 1X06_NO_SILK
J4, J12, J18, J24: 1X08_NO_SILK
J5, J10, J16, J22: QWIIC_RIGHT_ANGLE; JST04_1MM_RA
J6, J9, J15, J21: RASPBERRYPI-40-PIN-GPIO_SMD_STACK_NOHOLES_NOREF; RASPBERRY_PI_HAT_40_PIN_SMD_STACKABLE_NOHOLES_NOREF
JP1, JP2, JP3, JP4, JP9, JP10, JP11, JP12, JP15, JP16, JP17, JP18, JP21, JP22, JP23, JP24: JUMPER-SMT_2_NC_TRACE_SILK; SMT-JUMPER_2_NC_TRACE_SILK
JP5, JP8, JP14, JP20: JUMPER-SMT_2_NO_SILK; SMT-JUMPER_2_NO_SILK
JP6, JP7, JP13, JP19: JUMPER-SMT_3_2-NC_TRACE_SILK; SMT-JUMPER_3_2-NC_TRACE_SILK
LOGO1, LOGO6, LOGO9, LOGO12: QWIIC_LOGO_5MM; QWIIC_5MM
LOGO2, LOGO5, LOGO8, LOGO11: OSHW-LOGOM; OSHW-LOGO-M
LOGO3, LOGO4, LOGO7, LOGO10: SFE_LOGO_NAME_FLAME.2_INCH; SFE_LOGO_NAME_FLAME_.2
R1, R29, R53, R77: 100K; 0402
R2, R4, R32, R38, R56, R62, R80, R86: 33; 0603
R3, R5, R6, R7, R45, R46, R47, R48, R69, R70, R71, R72, R93, R94, R95, R96: 33; 1206_RA
R8, R10, R11, R12, R13, R25, R26, R30, R31, R37, R49, R50, R54, R55, R61, R73, R74, R78, R79, R85: 2.2k; 0603
R9, R28, R52, R76: 1k; 0603
R14, R15, R33, R34, R57, R58, R81, R82: 5.1k; 0402
R16, R19, R20, R27, R39, R41, R51, R63, R65, R75, R87, R89: 3.3k; 0603
R17, R18, R35, R36, R59, R60, R83, R84: 27; 0603
R21, R22, R43, R44, R67, R68, R91, R92: 910; 0603
R23, R24, R40, R42, R64, R66, R88, R90: 470; 0603
SHIELD, SHIELD1, SHIELD2, SHIELD3: JUMPER-SMT_2_NC_TRACE_SILK; SMT-JUMPER_2_NC_TRACE_SILK
TP1, TP2, TP3, TP4, TP5, TP6, TP7, TP8, TP9, TP10, TP11, TP12, TP13, TP14, TP15, TP16, TP17, TP18, TP19, TP20, TP21, TP22, TP23, TP24, TP25, TP26, TP27, TP28: TEST-POINT3X4; PAD.03X.04
U1, U8, U12, U16: U-BLOX_ZED-F9R; UBLOX_ZED_F9R
U2, U5, U9, U13: DUAL-OPTO_HCPL-073LSOIC-8; SO08
U3, U4, U6, U7, U10, U11, U14, U15: UHS_INVERTER_SCHMITT_TRIGGER_MPAK2; SIP6_MICROPAK2
U$1, U$48, U$92, U$136: ##RST##28
U$2, U$49, U$93, U$137: ##SFBT##30
U$3, U$59, U$103, U$147: PPS9
U$4, U$58, U$102, U$146: PWR7
U$5, U$61, U$105, U$149: GEO11
U$6, U$66, U$110, U$154: #RXI2#34
U$7, U$50, U$94, U$138: #INT#1
U$8, U$51, U$95, U$139: #PPS#3
U$9, U$30, U$89, U$133: SFE_LOGO_NAME_FLAME_.3@1
U$10, U$67, U$111, U$155: #TXO2#235
U$11, U$52, U$96, U$140: #W##2253
U$12, U$53, U$97, U$141: #W##2254
U$13, U$54, U$98, U$142: #D##2249
U$14, U$77, U$121, U$165: GNSS_DEAD_RECKONING25
U$15, U$55, U$99, U$143: #D##2250
U$16, U$68, U$112, U$156: ZED#F9R25
U$17, U$62, U$106, U$150: BLK22
U$18, U$19, U$64, U$65, U$108, U$109, U$152, U$153: #GND#20
U$20, U$56, U$100, U$144: #SPI#4
U$21, U$78, U$122, U$166: L1#L26
U$22, U$57, U$101, U$145: #I2C#5
U$23, U$60, U$104, U$148: RTK13
U$24, U$63, U$107, U$151: GRN23
U$25, U$28, U$85, U$86, U$129, U$130, U$173, U$174: Z20
U$26, U$29, U$87, U$88, U$131, U$132, U$175, U$176: Y19
U$27, U$45, U$83, U$84, U$127, U$128, U$171, U$172: X18
U$31, U$36, U$46, U$47, U$90, U$91, U$134, U$135: DEAD#RECKONING#GPS#BOARD#SILK#FINAL#JPG
U$32, U$69, U$113, U$157: ##RST##27
U$33, U$70, U$114, U$158: ##SFBT##29
U$34, U$71, U$115, U$159: #INT#0
U$35, U$72, U$116, U$160: #PPS#2
U$37, U$73, U$117, U$161: #W##2251
U$38, U$74, U$118, U$162: #W##2252
U$39, U$75, U$119, U$163: #D##2247
U$40, U$76, U$120, U$164: #D##2248
U$41, U$79, U$123, U$167: ANTENNA6
U$42, U$80, U$124, U$168: #TXO2#236
U$43, U$81, U$125, U$169: #RXI2#35
U$44, U$82, U$126, U$170: #SHLD#2258

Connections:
3.3V: C1.1, C2.1, C4.1, C7.1, C8.1, C10.1, D1.A, D3.A, D5.A, J5.2, J6.1, J6.1B, J6.17, J6.17B, JP6.2, R1.2, R21.2, R22.2, TP5.P$1, U1.P33, U1.P34, U1.P38, U2.8, U3.P6, U4.P6
3.3V1: C12.1, C15.1, C16.1, C17.1, C18.1, C20.1, D9.A, D10.A, D13.A, J9.1, J9.1B, J9.17, J9.17B, J10.2, JP7.2, R29.2, R43.2, R44.2, TP12.P$1, U5.8, U6.P6, U7.P6, U8.P33, U8.P34, U8.P38
3.3V2: C22.1, C25.1, C26.1, C27.1, C28.1, C30.1, D17.A, D18.A, D21.A, J15.1, J15.1B, J15.17, J15.17B, J16.2, JP13.2, R53.2, R67.2, R68.2, TP19.P$1, U9.8, U10.P6, U11.P6, U12.P33, U12.P34, U12.P38
3.3V3: C32.1, C35.1, C36.1, C37.1, C38.1, C40.1, D25.A, D26.A, D29.A, J21.1, J21.1B, J21.17, J21.17B, J22.2, JP19.2, R77.2, R91.2, R92.2, TP26.P$1, U13.8, U14.P6, U15.P6, U16.P33, U16.P34, U16.P38
5V: J6.2, J6.2B, J6.4, J6.4B
5V1: J9.2, J9.2B, J9.4, J9.4B
5V2: J15.2, J15.2B, J15.4, J15.4B
5V3: J21.2, J21.2B, J21.4, J21.4B
!RESET: J4.1, R3.P1
!RESET1: J12.1, R45.P1
!RESET2: J18.1, R69.P1
!RESET3: J24.1, R93.P1
!SAFEBOOT: J4.2, R3.P2
!SAFEBOOT1: J12.2, R45.P2
!SAFEBOOT2: J18.2, R69.P2
!SAFEBOOT3: J24.2, R93.P2
CE1: J6.26, J6.26B
CE2: J9.26, J9.26B
CE3: J15.26, J15.26B
CE4: J21.26, J21.26B
DIR+: J4.7, R20.1
DIR+1: J12.7, R41.1
DIR+2: J18.7, R65.1
DIR+3: J24.7, R89.1
DIR_IN: R23.2, U2.4
DIR_IN1: R42.2, U5.4
DIR_IN2: R66.2, U9.4
DIR_IN3: R90.2, U13.4
DIR_OUT: R6.P6, TP7.P$1, U4.P4
DIR_OUT1: R47.P6, TP14.P$1, U7.P4
DIR_OUT2: R71.P6, TP21.P$1, U11.P4
DIR_OUT3: R95.P6, TP28.P$1, U15.P4
DIR_SCHMITT: R22.1, U2.6, U4.P2
DIR_SCHMITT1: R44.1, U5.6, U7.P2
DIR_SCHMITT2: R68.1, U9.6, U11.P2
DIR_SCHMITT3: R92.1, U13.6, U15.P2
DMINUS: R18.2, U1.P39
DMINUS1: R36.2, U8.P39
DMINUS2: R60.2, U12.P39
DMINUS3: R84.2, U16.P39
DPLUS: R17.2, U1.P40
DPLUS1: R35.2, U8.P40
DPLUS2: R59.2, U12.P40
DPLUS3: R83.2, U16.P40
D_SEL: JP5.1, U1.P47
D_SEL1: JP8.1, U8.P47
D_SEL2: JP14.1, U12.P47
D_SEL3: JP20.1, U16.P47
GEOF_STAT: D4.A, R7.P7
GEOF_STAT1: D14.A, R48.P7
GEOF_STAT2: D22.A, R72.P7
GEOF_STAT3: D30.A, R96.P7
GND: BT1.-, C1.2, C2.2, C3.2, C4.2, C5.2, C6.2, C7.2, C8.2, C9.2, C10.2, D6.2, D7.1, D8.1, J1.1, J1.2, J2.GND, J2.GND2, J3.1, J4.6, J4.8, J5.1, J6.6, J6.6B, J6.9, J6.9B, J6.14, J6.14B, J6.20, J6.20B, J6.25, J6.25B, J6.30, J6.30B, J6.34, J6.34B, J6.39, J6.39B, JP1.1, JP2.1, JP4.1, JP5.2, R1.1, R14.1, R15.1, SHIELD.1, U1.G1, U1.G2, U1.G3, U1.G4, U1.G5, U1.G6, U1.G7, U1.G8, U1.G9, U1.G10, U1.G11, U1.G12, U1.G13, U1.G14, U1.G15, U1.G16, U1.G17, U1.G18, U1.G19, U1.G20, U1.G21, U1.G22, U1.G23, U1.G24, U1.G25, U1.G26, U1.G27, U1.G28, U1.G29, U1.G30, U1.G31, U1.G32, U1.G33, U1.G34, U1.G35, U1.G36, U1.G37, U1.G38, U1.G39, U1.G40, U1.G41, U1.G42, U1.G43, U1.G44, U1.G45, U1.G46, U1.G47, U1.G48, U1.P1, U1.P3, U1.P12, U1.P14, U1.P32, U1.P37, U1.P41, U1.P48, U2.2, U2.3, U2.5, U3.P3, U4.P3
GND1: BT2.-, C11.2, C12.2, C13.2, C14.2, C15.2, C16.2, C17.2, C18.2, C19.2, C20.2, D11.2, D15.1, D16.1, J7.1, J7.2, J8.GND, J8.GND2, J9.6, J9.6B, J9.9, J9.9B, J9.14, J9.14B, J9.20, J9.20B, J9.25, J9.25B, J9.30, J9.30B, J9.34, J9.34B, J9.39, J9.39B, J10.1, J11.1, J12.6, J12.8, JP8.2, JP9.1, JP11.1, JP12.1, R29.1, R33.1, R34.1, SHIELD1.1, U5.2, U5.3, U5.5, U6.P3, U7.P3, U8.G1, U8.G2, U8.G3, U8.G4, U8.G5, U8.G6, U8.G7, U8.G8, U8.G9, U8.G10, U8.G11, U8.G12, U8.G13, U8.G14, U8.G15, U8.G16, U8.G17, U8.G18, U8.G19, U8.G20, U8.G21, U8.G22, U8.G23, U8.G24, U8.G25, U8.G26, U8.G27, U8.G28, U8.G29, U8.G30, U8.G31, U8.G32, U8.G33, U8.G34, U8.G35, U8.G36, U8.G37, U8.G38, U8.G39, U8.G40, U8.G41, U8.G42, U8.G43, U8.G44, U8.G45, U8.G46, U8.G47, U8.G48, U8.P1, U8.P3, U8.P12, U8.P14, U8.P32, U8.P37, U8.P41, U8.P48
GND2: BT3.-, C21.2, C22.2, C23.2, C24.2, C25.2, C26.2, C27.2, C28.2, C29.2, C30.2, D19.2, D23.1, D24.1, J13.1, J13.2, J14.GND, J14.GND2, J15.6, J15.6B, J15.9, J15.9B, J15.14, J15.14B, J15.20, J15.20B, J15.25, J15.25B, J15.30, J15.30B, J15.34, J15.34B, J15.39, J15.39B, J16.1, J17.1, J18.6, J18.8, JP14.2, JP15.1, JP17.1, JP18.1, R53.1, R57.1, R58.1, SHIELD2.1, U9.2, U9.3, U9.5, U10.P3, U11.P3, U12.G1, U12.G2, U12.G3, U12.G4, U12.G5, U12.G6, U12.G7, U12.G8, U12.G9, U12.G10, U12.G11, U12.G12, U12.G13, U12.G14, U12.G15, U12.G16, U12.G17, U12.G18, U12.G19, U12.G20, U12.G21, U12.G22, U12.G23, U12.G24, U12.G25, U12.G26, U12.G27, U12.G28, U12.G29, U12.G30, U12.G31, U12.G32, U12.G33, U12.G34, U12.G35, U12.G36, U12.G37, U12.G38, U12.G39, U12.G40, U12.G41, U12.G42, U12.G43, U12.G44, U12.G45, U12.G46, U12.G47, U12.G48, U12.P1, U12.P3, U12.P12, U12.P14, U12.P32, U12.P37, U12.P41, U12.P48
GND3: BT4.-, C31.2, C32.2, C33.2, C34.2, C35.2, C36.2, C37.2, C38.2, C39.2, C40.2, D27.2, D31.1, D32.1, J19.1, J19.2, J20.GND, J20.GND2, J21.6, J21.6B, J21.9, J21.9B, J21.14, J21.14B, J21.20, J21.20B, J21.25, J21.25B, J21.30, J21.30B, J21.34, J21.34B, J21.39, J21.39B, J22.1, J23.1, J24.6, J24.8, JP20.2, JP21.1, JP23.1, JP24.1, R77.1, R81.1, R82.1, SHIELD3.1, U13.2, U13.3, U13.5, U14.P3, U15.P3, U16.G1, U16.G2, U16.G3, U16.G4, U16.G5, U16.G6, U16.G7, U16.G8, U16.G9, U16.G10, U16.G11, U16.G12, U16.G13, U16.G14, U16.G15, U16.G16, U16.G17, U16.G18, U16.G19, U16.G20, U16.G21, U16.G22, U16.G23, U16.G24, U16.G25, U16.G26, U16.G27, U16.G28, U16.G29, U16.G30, U16.G31, U16.G32, U16.G33, U16.G34, U16.G35, U16.G36, U16.G37, U16.G38, U16.G39, U16.G40, U16.G41, U16.G42, U16.G43, U16.G44, U16.G45, U16.G46, U16.G47, U16.G48, U16.P1, U16.P3, U16.P12, U16.P14, U16.P32, U16.P37, U16.P41, U16.P48
GP1: J9.31, J9.31B
GP2: J9.32, J9.32B
GP3: J9.33, J9.33B
GP4: J6.7, J6.7B
GP5: J9.36, J9.36B
GP6: J6.31, J6.31B
GP7: J9.35, J9.35B
GP8: J9.38, J9.38B
GP9: J9.40, J9.40B
GP10: J9.37, J9.37B
GP11: J9.7, J9.7B
GP12: J6.32, J6.32B
GP13: J6.33, J6.33B
GP14: J9.11, J9.11B
GP15: J9.12, J9.12B
GP16: J6.36, J6.36B
GP17: J6.11, J6.11B
GP18: J6.12, J6.12B
GP19: J6.35, J6.35B
GP20: J6.38, J6.38B
GP21: J6.40, J6.40B
GP22: J6.15, J6.15B
GP23: J6.16, J6.16B
GP24: J6.18, J6.18B
GP25: J6.22, J6.22B
GP26: J6.37, J6.37B
GP27: J6.13, J6.13B
GP28: J9.15, J9.15B
GP29: J9.16, J9.16B
GP30: J9.18, J9.18B
GP31: J9.22, J9.22B
GP32: J9.13, J9.13B
GP33: J15.31, J15.31B
GP34: J15.32, J15.32B
GP35: J15.33, J15.33B
GP36: J15.36, J15.36B
GP37: J15.35, J15.35B
GP38: J15.38, J15.38B
GP39: J15.40, J15.40B
GP40: J15.37, J15.37B
GP41: J15.7, J15.7B
GP42: J15.11, J15.11B
GP43: J15.12, J15.12B
GP44: J15.15, J15.15B
GP45: J15.16, J15.16B
GP46: J15.18, J15.18B
GP47: J15.22, J15.22B
GP48: J15.13, J15.13B
GP49: J21.31, J21.31B
GP50: J21.32, J21.32B
GP51: J21.33, J21.33B
GP52: J21.36, J21.36B
GP53: J21.35, J21.35B
GP54: J21.38, J21.38B
GP55: J21.40, J21.40B
GP56: J21.37, J21.37B
GP57: J21.7, J21.7B
GP58: J21.11, J21.11B
GP59: J21.12, J21.12B
GP60: J21.15, J21.15B
GP61: J21.16, J21.16B
GP62: J21.18, J21.18B
GP63: J21.22, J21.22B
GP64: J21.13, J21.13B
ID_SC: J6.28, J6.28B
ID_SC1: J9.28, J9.28B
ID_SC2: J15.28, J15.28B
ID_SC3: J21.28, J21.28B
ID_SD: J6.27, J6.27B
ID_SD1: J9.27, J9.27B
ID_SD2: J15.27, J15.27B
ID_SD3: J21.27, J21.27B
INT: J4.3, R3.P3
INT1: J12.3, R45.P3
INT2: J18.3, R69.P3
INT3: J24.3, R93.P3
unnamed: JP6.1, R13.2
unnamed: D5.C, R16.2
unnamed: JP6.3, R8.2
unnamed: D1.C, R9.2
unnamed: C3.1, FB1.P2, R2.1
unnamed: D6.6, R18.1
unnamed: D6.4, R17.1
unnamed: JP1.2, R9.1
unnamed: D6.3, J2.A6, J2.B6
unnamed: D6.5, J2.VBUS1, J2.VBUS2
unnamed: D6.1, J2.A7, J2.B7
unnamed: J2.B5, R14.2
unnamed: R3.P8, U1.P49
unnamed: R3.P6, U1.P51
unnamed: R5.P6, U1.P44
unnamed: JP4.2, R12.1
unnamed: D4.C, R12.2
unnamed: J2.A5, R15.2
unnamed: R5.P5, U1.P45
unnamed: R4.1, U1.P46
unnamed: R5.P8, U1.P42
unnamed: JP3.2, R11.1
unnamed: JP2.2, R10.1
unnamed: D2.C, R10.2
unnamed: D3.C, R11.2
unnamed: R5.P7, U1.P43
unnamed: C6.1, D8.3, R19.2, R24.1
unnamed: R7.P2, U1.P19
unnamed: R7.P1, U1.P20
unnamed: R3.P5, U1.P53
unnamed: R3.P7, U1.P50
unnamed: R6.P1, U1.P27
unnamed: R6.P2, U1.P26
unnamed: R6.P4, U1.P22
unnamed: R6.P3, U1.P23
unnamed: C5.1, D7.3, R20.2, R23.1
unnamed: D9.C, R27.2
unnamed: JP7.1, R25.2
unnamed: JP7.3, R26.2
unnamed: JP10.2, R31.1
unnamed: JP11.2, R30.1
unnamed: D12.C, R30.2
unnamed: D13.C, R31.2
unnamed: D10.C, R28.2
unnamed: JP9.2, R28.1
unnamed: C11.1, FB2.P2, R32.1
unnamed: J8.B5, R33.2
unnamed: J8.A5, R34.2
unnamed: D11.5, J8.VBUS1, J8.VBUS2
unnamed: D11.3, J8.A6, J8.B6
unnamed: D11.1, J8.A7, J8.B7
unnamed: D11.6, R36.1
unnamed: D11.4, R35.1
unnamed: JP12.2, R37.1
unnamed: D14.C, R37.2
unnamed: R45.P8, U8.P49
unnamed: R45.P6, U8.P51
unnamed: R46.P6, U8.P44
unnamed: R46.P5, U8.P45
unnamed: R38.1, U8.P46
unnamed: R46.P8, U8.P42
unnamed: R46.P7, U8.P43
unnamed: R48.P2, U8.P19
unnamed: R48.P1, U8.P20
unnamed: R45.P5, U8.P53
unnamed: R45.P7, U8.P50
unnamed: R47.P1, U8.P27
unnamed: R47.P2, U8.P26
unnamed: R47.P4, U8.P22
unnamed: R47.P3, U8.P23
unnamed: C14.1, D15.3, R39.2, R40.1
unnamed: C13.1, D16.3, R41.2, R42.1
unnamed: D17.C, R51.2
unnamed: JP13.1, R49.2
unnamed: JP13.3, R50.2
unnamed: JP16.2, R55.1
unnamed: JP17.2, R54.1
unnamed: D20.C, R54.2
unnamed: D21.C, R55.2
unnamed: D18.C, R52.2
unnamed: JP15.2, R52.1
unnamed: C21.1, FB3.P2, R56.1
unnamed: J14.B5, R57.2
unnamed: J14.A5, R58.2
unnamed: D19.5, J14.VBUS1, J14.VBUS2
unnamed: D19.3, J14.A6, J14.B6
unnamed: D19.1, J14.A7, J14.B7
unnamed: D19.6, R60.1
unnamed: D19.4, R59.1
unnamed: JP18.2, R61.1
unnamed: D22.C, R61.2
unnamed: R69.P8, U12.P49
unnamed: R69.P6, U12.P51
unnamed: R70.P6, U12.P44
unnamed: R70.P5, U12.P45
unnamed: R62.1, U12.P46
unnamed: R70.P8, U12.P42
unnamed: R70.P7, U12.P43
unnamed: R72.P2, U12.P19
unnamed: R72.P1, U12.P20
unnamed: R69.P5, U12.P53
unnamed: R69.P7, U12.P50
unnamed: R71.P1, U12.P27
unnamed: R71.P2, U12.P26
unnamed: R71.P4, U12.P22
unnamed: R71.P3, U12.P23
unnamed: C24.1, D23.3, R63.2, R64.1
unnamed: C23.1, D24.3, R65.2, R66.1
unnamed: D25.C, R75.2
unnamed: JP19.1, R73.2
unnamed: JP19.3, R74.2
unnamed: JP22.2, R79.1
unnamed: JP23.2, R78.1
unnamed: D28.C, R78.2
unnamed: D29.C, R79.2
unnamed: D26.C, R76.2
unnamed: JP21.2, R76.1
unnamed: C31.1, FB4.P2, R80.1
unnamed: J20.B5, R81.2
unnamed: J20.A5, R82.2
unnamed: D27.5, J20.VBUS1, J20.VBUS2
unnamed: D27.3, J20.A6, J20.B6
unnamed: D27.1, J20.A7, J20.B7
unnamed: D27.6, R84.1
unnamed: D27.4, R83.1
unnamed: JP24.2, R85.1
unnamed: D30.C, R85.2
unnamed: R93.P8, U16.P49
unnamed: R93.P6, U16.P51
unnamed: R94.P6, U16.P44
unnamed: R94.P5, U16.P45
unnamed: R86.1, U16.P46
unnamed: R94.P8, U16.P42
unnamed: R94.P7, U16.P43
unnamed: R96.P2, U16.P19
unnamed: R96.P1, U16.P20
unnamed: R93.P5, U16.P53
unnamed: R93.P7, U16.P50
unnamed: R95.P1, U16.P27
unnamed: R95.P2, U16.P26
unnamed: R95.P4, U16.P22
unnamed: R95.P3, U16.P23
unnamed: C34.1, D31.3, R87.2, R88.1
unnamed: C33.1, D32.3, R89.2, R90.1
PPS: D2.A, J4.4, R3.P4
PPS1: D12.A, J12.4, R45.P4
PPS2: D20.A, J18.4, R69.P4
PPS3: D28.A, J24.4, R93.P4
QWIIC_SCL: J5.4, J6.5, J6.5B, R8.1
QWIIC_SCL1: J9.5, J9.5B, J10.4, R26.1
QWIIC_SCL2: J15.5, J15.5B, J16.4, R50.1
QWIIC_SCL3: J21.5, J21.5B, J22.4, R74.1
QWIIC_SDA: J5.3, J6.3, J6.3B, R13.1
QWIIC_SDA1: J9.3, J9.3B, J10.3, R25.1
QWIIC_SDA2: J15.3, J15.3B, J16.3, R49.1
QWIIC_SDA3: J21.3, J21.3B, J22.3, R73.1
RF_IN: FB1.P1, J1.FEED, U1.P2
RF_IN1: FB2.P1, J7.FEED, U8.P2
RF_IN2: FB3.P1, J13.FEED, U12.P2
RF_IN3: FB4.P1, J19.FEED, U16.P2
RTK_STAT: JP3.1, R7.P8
RTK_STAT1: JP10.1, R48.P8
RTK_STAT2: JP16.1, R72.P8
RTK_STAT3: JP22.1, R96.P8
RXI1: J11.4, R47.P7
RXI2: J3.4, R6.P7
RXI3: J17.4, R71.P7
RXI4: J23.4, R95.P7
RXI/CIPO: J6.8, J6.8B, J6.19, J6.19B, R5.P2, TP1.P$1
RXI/CIPO1: J9.8, J9.8B, J9.19, J9.19B, R46.P2, TP8.P$1
RXI/CIPO2: J15.8, J15.8B, J15.19, J15.19B, R70.P2, TP15.P$1
RXI/CIPO3: J21.8, J21.8B, J21.19, J21.19B, R94.P2, TP22.P$1
SCL/CLK: J6.23, J6.23B, R5.P4, TP3.P$1
SCL/CLK1: J9.23, J9.23B, R46.P4, TP10.P$1
SCL/CLK2: J15.23, J15.23B, R70.P4, TP17.P$1
SCL/CLK3: J21.23, J21.23B, R94.P4, TP24.P$1
SDA/!CS: J6.24, J6.24B, R5.P3, TP4.P$1
SDA/!CS1: J9.24, J9.24B, R46.P3, TP11.P$1
SDA/!CS2: J15.24, J15.24B, R70.P3, TP18.P$1
SDA/!CS3: J21.24, J21.24B, R94.P3, TP25.P$1
SHIELD: J2.SHLD1, J2.SHLD2, J2.SHLD3, J2.SHLD4, SHIELD.2
SHIELD1: J8.SHLD1, J8.SHLD2, J8.SHLD3, J8.SHLD4, SHIELD1.2
SHIELD2: J14.SHLD1, J14.SHLD2, J14.SHLD3, J14.SHLD4, SHIELD2.2
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

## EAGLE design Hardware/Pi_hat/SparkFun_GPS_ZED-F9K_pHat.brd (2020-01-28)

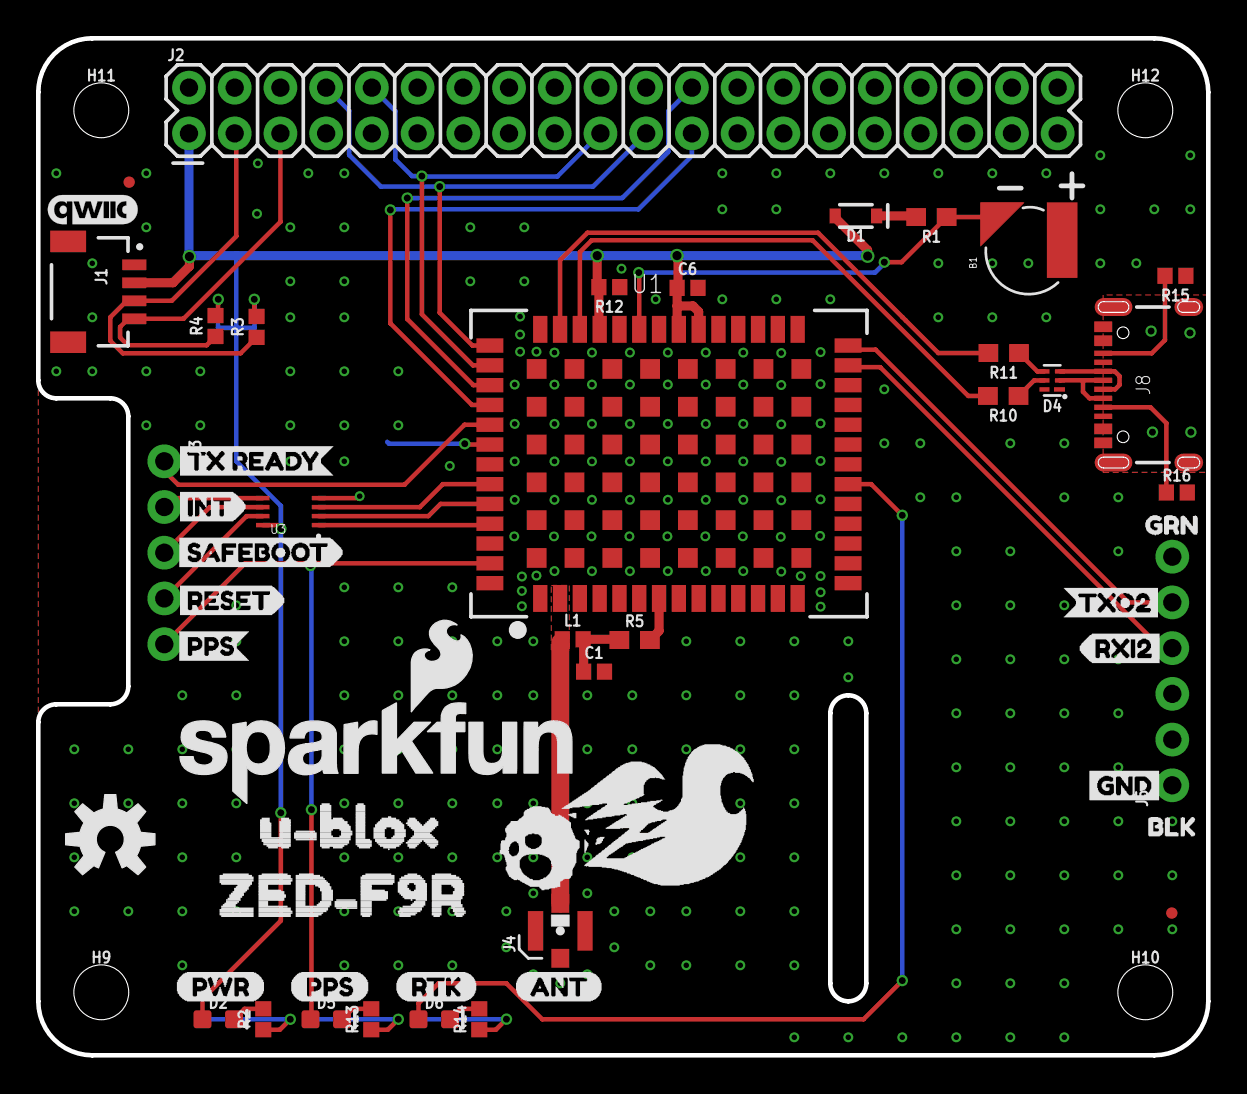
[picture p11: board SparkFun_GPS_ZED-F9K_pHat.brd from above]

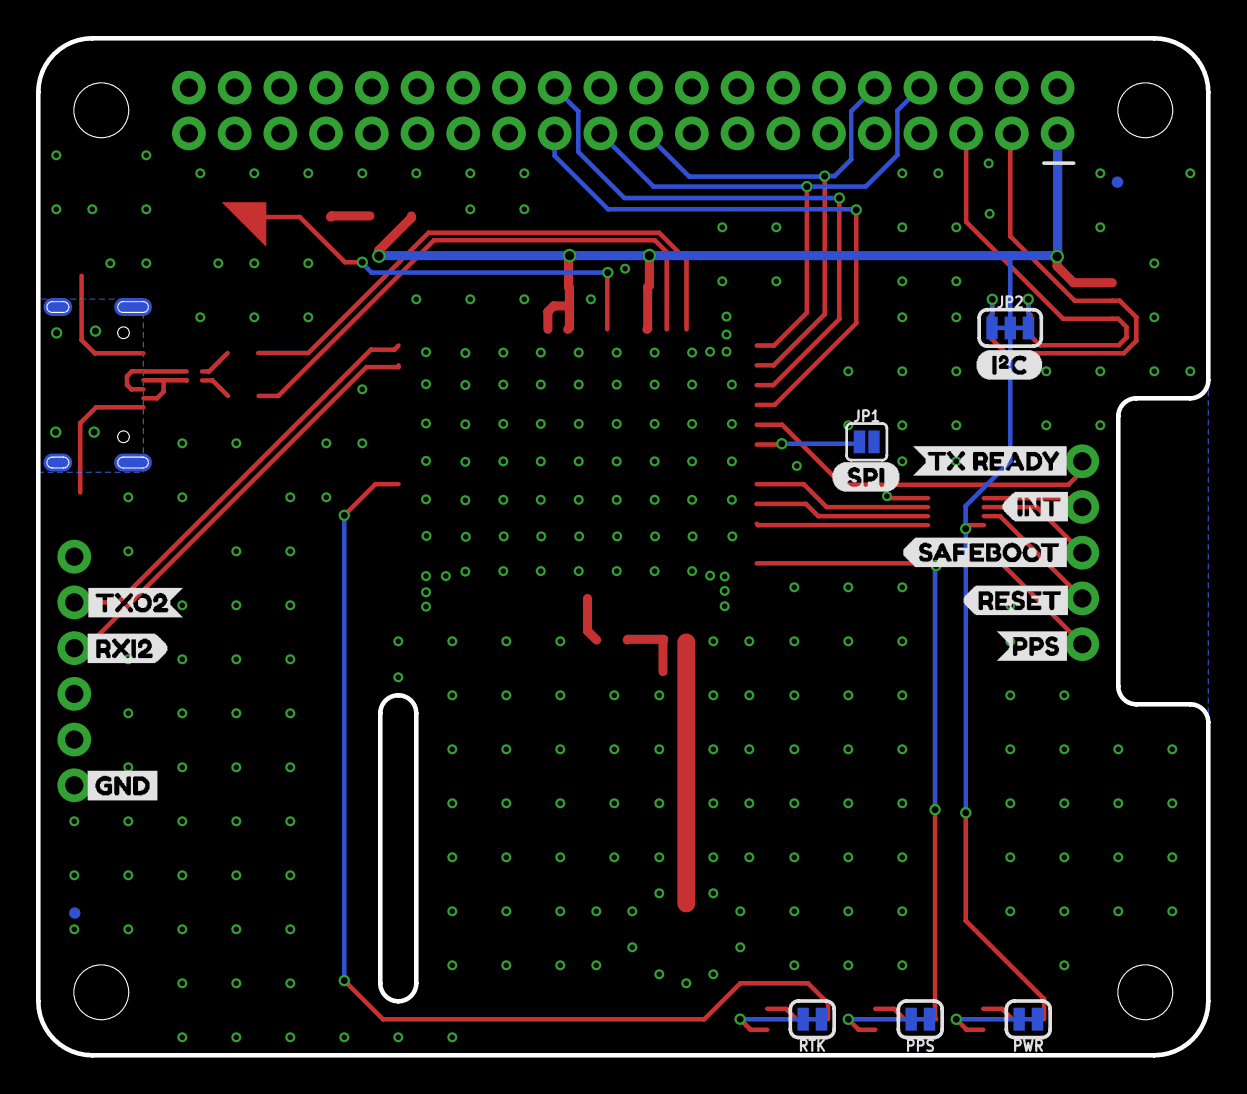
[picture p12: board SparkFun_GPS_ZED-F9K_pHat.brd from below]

Board: 2 copper layers, 65.0 x 56.5 mm, 73 parts (17 on the bottom side), 43 nets.

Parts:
B1: ML414H_IV01E_BATTERY; ML414H_IV01E
C1: 0.1uF; 0402
C6: 1.0uF; 0402
D1: 0.5A/40V/420mV; SOD-323
D2: RED; LED-0603
D4: PRTR5V0U2F; SOT886
D5, D6: BLUE; LED-0603
FD9, FD10, FD11, FD12: FIDUCIALUFIDUCIAL; FIDUCIAL-MICRO
FRAME2: FRAME-LEDGER; CREATIVE_COMMONS
H9, H10, H11, H12: STAND-OFFTIGHT; STAND-OFF-TIGHT
J1: QWIIC_RIGHT_ANGLE; JST04_1MM_RA
J2: RASPBERRYPI-40-PIN-GPIO_PTH_NO_SHROUD; 2X20
J3: 1X05_NO_SILK
J4: U.FL
J5: 1X06_NO_SILK
J8: USB-C-16P
JP1: JUMPER-SMT_2_NO_SILK; SMT-JUMPER_2_NO_SILK
JP2: JUMPER-SMT_3_2-NC_TRACE_SILK; SMT-JUMPER_3_2-NC_TRACE_SILK
L1: 3.9NH; 0402
LOGO1: SFE_LOGO_NAME_FLAME.2_INCH; SFE_LOGO_NAME_FLAME_.2
LOGO2: OSHW-LOGOM; OSHW-LOGO-M
LOGO3: QWIIC_LOGO_5MM; QWIIC_5MM
PPS: JUMPER-SMT_2_NC_TRACE_SILK; SMT-JUMPER_2_NC_TRACE_SILK
PWR: JUMPER-SMT_2_NC_TRACE_SILK; SMT-JUMPER_2_NC_TRACE_SILK
R1: 3.3k; 0603
R2, R13, R14: 1KOHM-0402-1/16W-1%; 0402
R3, R4: 2.2K; 0402
R5: 20; 0603
R10, R11: 27; 0603
R12: 100K; 0402
R15, R16: 5.1k; 0402
RTK: JUMPER-SMT_2_NC_TRACE_SILK; SMT-JUMPER_2_NC_TRACE_SILK
U1: UBLOX_ZED_F9K
U3: TRIPLE_BUFFER_74LVC3G07; SOP_8-PIN
U$1: INT1
U$2: PPS4
U$3: PPS6
U$4: PWR7
U$5: RTK5
U$6: RXI28
U$7: SAFEBOOT2
U$8: RESET0
U$9, U$17: TX_READY0
U$10: TXO21
U$11: INT2
U$12: PPS1
U$13: RESET4
U$14: RXI26
U$15: SAFEBOOT3
U$16: TXO25
U$18, U$19: GND-04
U$20: I_SUPER2_C-()-04
U$21: ANT1
U$22: BLK3
U$23: GRN2
U$24: SPI0
U$25: U#BLOX1
U$26: ZED#F9R0
U$27: NEO_GPS_BOARD_SILK_FINAL#03#JPG

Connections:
3.3V: C6.1, D1.A, D2.A, J1.2, J2.1, J2.17, JP2.2, R12.2, U1.P33, U1.P34, U1.P38, U3.P8
5V: J2.2, J2.4
!RESET_IN: U1.P49, U3.P3
!RESET_OUT: J3.4, U3.P7
!SAFEBOOT_IN: J3.3, U3.P6
!SAFEBOOT_OUT: U1.P50, U3.P2
DMINUS: R10.2, U1.P39
DPLUS: R11.2, U1.P40
D_SEL: JP1.1, U1.P47
GND: B1.-, C1.2, C6.2, J1.1, J2.6, J2.9, J2.14, J2.20, J2.25, J2.30, J2.34, J2.39, J4.1, J4.2, J5.1, J8.GND, J8.GND2, JP1.2, PPS.1, PWR.1, R12.1, R15.1, R16.1, RTK.1, U1.G1, U1.G2, U1.G3, U1.G4, U1.G5, U1.G6, U1.G7, U1.G8, U1.G9, U1.G10, U1.G11, U1.G12, U1.G13, U1.G14, U1.G15, U1.G16, U1.G17, U1.G18, U1.G19, U1.G20, U1.G21, U1.G22, U1.G23, U1.G24, U1.G25, U1.G26, U1.G27, U1.G28, U1.G29, U1.G30, U1.G31, U1.G32, U1.G33, U1.G34, U1.G35, U1.G36, U1.G37, U1.G38, U1.G39, U1.G40, U1.G41, U1.G42, U1.G43, U1.G44, U1.G45, U1.G46, U1.G47, U1.G48, U1.P1, U1.P3, U1.P12, U1.P14, U1.P32, U1.P37, U1.P41, U1.P48, U3.P4
INT_IN: U1.P51, U3.P1
INT_OUT: J3.2, U3.P5
unnamed: JP2.1, R3.2
unnamed: D1.C, R1.2
unnamed: JP2.3, R4.2
unnamed: D2.C, R2.2
unnamed: C1.1, L1.2, R5.1
unnamed: PWR.2, R2.1
unnamed: J8.B5, R15.2
unnamed: D4.5, R10.1
unnamed: D4.4, R11.1
unnamed: J8.A5, R16.2
unnamed: R14.1, RTK.2
unnamed: PPS.2, R13.1
unnamed: D5.C, R13.2
unnamed: D6.C, R14.2
PPS: D5.A, J3.5, U1.P53
QWIIC_SCL: J1.4, J2.5, R4.1
QWIIC_SDA: J1.3, J2.3, R3.1
RF_IN: J4.FEED, L1.1, U1.P2
RTK_STAT: D6.A, U1.P20
RXI2: J5.4, U1.P26
RXI/MOSI: J2.10, J2.19, U1.P43
SCL/CLK: J2.23, U1.P45
SDA/!CS: J2.24, U1.P44
SHIELD: J8.SHLD1, J8.SHLD2, J8.SHLD3, J8.SHLD4, J8.SHLD5, J8.SHLD6, J8.SHLD7, J8.SHLD8
TXO2: J5.5, U1.P27
TXO/MISO: J2.8, J2.21, U1.P42
TX_READY: J3.1, U1.P46
USB_D+: D4.3, J8.A6, J8.B6
USB_D-: D4.2, J8.A7, J8.B7
V_BATT: B1.+, R1.1, U1.P36
V_RF: R5.2, U1.P7

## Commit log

2019-10-10 Adds basic layout to board and creates (most of) ZED-F9K device
    [SparkFun_GPS_ZED-F9K.brd, SparkFun_GPS_ZED-F9K.sch]
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2019-10-10 Adds circuitry for active antenna or RF_IN
    [SparkFun_GPS_ZED-F9K.brd, SparkFun_GPS_ZED-F9K.sch]
2019-10-11 Adds power circuitry with ESD protection, adds LEDs
    [SparkFun_GPS_ZED-F9K.brd, SparkFun_GPS_ZED-F9K.sch]
2019-10-24 Adds I/O protection to INPUTS using new part, removes active antenna circuitry in place of VCC bias for external patch active antennas
    * Localizes parts into a rough shape for final product
    [SparkFun_GPS_ZED-F9K.brd, SparkFun_GPS_ZED-F9K.sch]
2019-10-24 Just some light trace work to get a feel for layout
    [SparkFun_GPS_ZED-F9K.brd]
2020-01-08 Adds micro pi hat layout
    [SparkFun_GPS_ZED-F9K_uHat.brd, SparkFun_GPS_ZED-F9K_uHat.sch]
2020-01-09 Adds trace work for piHat version - still needs silk
    [SparkFun_GPS_ZED-F9K_uHat.brd, SparkFun_GPS_ZED-F9K_uHat.sch]
2020-01-20 Replaces micro hat with regular hat
    [SparkFun_GPS_ZED-F9K_uHat.brd, SparkFun_GPS_ZED-F9K_uHat.sch]
2020-01-20 Renames files to reflect change to pi hat
    [SparkFun_GPS_ZED-F9K_pHat.brd, SparkFun_GPS_ZED-F9K_pHat.sch]
2020-01-20 Add prelimnary trace routing
    [SparkFun_GPS_ZED-F9K_pHat.brd]
2020-01-20 Adds nets for data lines
    [SparkFun_GPS_ZED-F9K_pHat.brd, SparkFun_GPS_ZED-F9K_pHat.sch]
2020-01-21 Finishes pi hat design and adds some labels
    [SparkFun_GPS_ZED-F9K_pHat.brd, SparkFun_GPS_ZED-F9K_pHat.sch]
2020-01-22 Solidifies breakout board size
    [SparkFun_GPS_ZED-F9K.brd, SparkFun_GPS_ZED-F9K.sch]
2020-01-24 Finalizes trace work for the Breakout board
    [SparkFun_GPS_ZED-F9K.brd, SparkFun_GPS_ZED-F9K.sch]
2020-01-24 Adds a few more vias
    [SparkFun_GPS_ZED-F9K.brd]
2020-01-27 Updates Modules, adjusts ground pour.
    [SparkFun_GPS_ZED-F9K.brd, SparkFun_GPS_ZED-F9K.sch]
2020-01-27 More work to ground pour
    [SparkFun_GPS_ZED-F9K.brd, SparkFun_GPS_ZED-F9K.sch]
2020-01-27 Fixes a few traces
    [SparkFun_GPS_ZED-F9K.brd]
2020-01-28 Adds labels to breakout board
    [SparkFun_GPS_ZED-F9K.brd, SparkFun_GPS_ZED-F9K.sch]
2020-01-28 Adds labels to pi hat
    [SparkFun_GPS_ZED-F9K_pHat.brd]
2020-01-28 Adds labels to the pi-hat
    [SparkFun_GPS_ZED-F9K_pHat.brd, SparkFun_GPS_ZED-F9K_pHat.sch]
2020-01-29 Fixes labels on BoB
    [SparkFun_GPS_ZED-F9K.brd, SparkFun_GPS_ZED-F9K.sch]
2020-01-31 Moves buzzard labels to their own folder - updates breakout board with better labeling
    * fixes I2C lines being backwards
    * Moves D+ and D- lines around
    [SparkFun_GPS_ZED-F9K.brd, SparkFun_GPS_ZED-F9K.sch, SparkFun_GPS_ZED-F9K_pHat.brd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]
2020-01-31 Adjust pi-hat design
    * Moves jumpers to teh top
    * moves labels for LEDs to teh Edge
    * Moves USB and FTDI header to the bottom edge
    * Fixes ESD protection IC routing
    * Fixes RX/TX
    [SparkFun_GPS_ZED-F9K_pHat.brd, SparkFun_GPS_ZED-F9K_pHat.sch]
2020-01-31 Fixes routing for ESD protection IC
    [SparkFun_GPS_ZED-F9K.brd, SparkFun_GPS_ZED-F9K.sch]
2020-02-04 Replaces some 0402 components for 0603 on the pi-hat
    [SparkFun_GPS_ZED-F9K_pHat.brd, SparkFun_GPS_ZED-F9K_pHat.sch]
2020-02-11 Adds F9R datasheets, updates design with wheel ticks, direction pins, and adds 33 Ohm filtering resistors to all I/O
    [SparkFun_GPS_ZED-F9K_pHat.brd, SparkFun_GPS_ZED-F9K_pHat.sch]
2020-02-11 Updates breakout board with the same parts as the pi hat
    [SparkFun_GPS_ZED-F9K.brd, SparkFun_GPS_ZED-F9K.sch]
2020-02-12 Touches up some vias and traces
    [SparkFun_GPS_ZED-F9K.brd, SparkFun_GPS_ZED-F9K.sch]
2020-02-13 Gerbers for both boards
    [SparkFun_GPS_ZED-F9K.GBL, SparkFun_GPS_ZED-F9K.GBO, SparkFun_GPS_ZED-F9K.GBP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]
2020-02-14 Moves library, adds breakout board - circuit for wheel ticks and direction input
    [WheelDir_BoB.brd, WheelDir_BoB.sch]
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2020-02-17 Adds the automotive interface breakout board
    [WheelDir_BoB.brd, WheelDir_BoB.sch]
2020-02-17 Renames wheelDir_BoB To Automotive Interafce BoB
    [Automotive_Inter_BoB.brd, Automotive_Inter_BoB.sch]
2020-02-17 Updates the optocoupler in the Automotive breakout
    [Automotive_Inter_BoB.brd, Automotive_Inter_BoB.sch]
2020-02-17 Updates schmitt trigger on Automoative Interface board
    [Automotive_Inter_BoB.brd, Automotive_Inter_BoB.sch]
2020-02-17 CAMs the Automotive Interface Board, updates parts in library with digikey links
    [Automotive_Inter_BoB.GBL, Automotive_Inter_BoB.GBO, Automotive_Inter_BoB.GBP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]
2020-02-25 Changes PTH header to double SMD male/femail combination
    [SparkFun_GPS_ZED-F9K_pHat.brd, SparkFun_GPS_ZED-F9K_pHat.sch]
2020-02-27 Adds test point for power
    [SparkFun_GPS_ZED-F9K_pHat.brd, SparkFun_GPS_ZED-F9K_pHat.sch]
2020-03-18 Adds wheel tick and direction circuit to pi-hat
    [Automotive_Inter_BoB.brd, Automotive_Inter_BoB.sch, SparkFun_GPS_ZED-F9K_pHat.brd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]
2020-03-18 Routes wheel tick and direction circuitry
    [SparkFun_GPS_ZED-F9K_pHat.brd, SparkFun_GPS_ZED-F9K_pHat.sch]
2020-03-23 Adds automotive certified diode to wt/dir circuitry
    * Adds wt/dir circuitry to both breakout board and pi hat
    [Automotive_Inter_BoB.brd, SparkFun_GPS_ZED-F9K.brd, SparkFun_GPS_ZED-F9K.sch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]
2020-03-23 Adds labels for new PTH for wt/dir lines
    [SparkFun_GPS_ZED-F9K.brd, SparkFun_GPS_ZED-F9K_pHat.brd]
2020-03-23 Updates designs with new X7R capacitors
    [SparkFun_GPS_ZED-F9K.brd, SparkFun_GPS_ZED-F9K.sch, SparkFun_GPS_ZED-F9K_pHat.brd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]
2020-03-26 Removes gerbers, removes caps from schmitt trigger on both designs, adds 1uF cap to V_USB on breakout
    [Automotive_Inter_BoB.GBL, Automotive_Inter_BoB.GBO, Automotive_Inter_BoB.GBP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]
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2020-03-27 Updates wheel tick and direction circuitry with correct grounding
    [Automotive_Inter_BoB.brd, Automotive_Inter_BoB.sch, SparkFun_GPS_ZED-F9K.brd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]
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2020-03-27 Renames files to correct module
    [SparkFun_GPS_ZED-F9R_pHat.brd, SparkFun_GPS_ZED-F9R_pHat.sch]
2020-03-27 Replaces 9-pin connector with 8-pin
    [SparkFun_GPS_ZED-F9R_pHat.brd, SparkFun_GPS_ZED-F9R_pHat.sch]
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2020-03-28 Fixe RF trace, fixes silk, moves version number, fixes D+ and D- traces
    * Changes jumper labels in schematic
    [SparkFun_GPS_ZED-F9R_pHat.brd, SparkFun_GPS_ZED-F9R_pHat.sch]
2020-03-28 Updates silk, fixes RF trace, moves some traces for better clearance, adds wt/dir text to schematic
    [SparkFun_GPS_ZED-F9R_pHat.brd, SparkFun_GPS_ZED-F9R_pHat.sch]
2020-03-31 Adds 33 Ohm resistor arrays and custom silk
    [SparkFun_GPS_ZED-F9R_pHat.brd, SparkFun_GPS_ZED-F9R_pHat.sch]
2020-03-31 Updates all parts to parts in the Eagle Library
    [SparkFun_GPS_ZED-F9R_pHat.brd, SparkFun_GPS_ZED-F9R_pHat.sch]
2020-03-31 Replaces 910 Ohm resistor with part from Eagle Library
    [SparkFun_GPS_ZED-F9R_pHat.brd, SparkFun_GPS_ZED-F9R_pHat.sch]
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2020-03-31 Adds Panel, removes buzzard labels
    [SparkFun_GPS_ZED-F9R_pHat-Panel.GBL, SparkFun_GPS_ZED-F9R_pHat-Panel.GBO, SparkFun_GPS_ZED-F9R_pHat-Panel.GBP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]
2020-03-31 Fixes issue with panel
    [SparkFun_GPS_ZED-F9R_pHat-Panel.brd, SparkFun_GPS_ZED-F9R_pHat.brd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]
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2020-04-03 Replaces 6.3V rated 0.1uF caps with 10V rated ones
    [SparkFun_GPS_ZED-F9R_pHat.brd, SparkFun_GPS_ZED-F9R_pHat.sch]
2020-04-03 Replaces one of the .1uF with a 1uF Capacitor
    [SparkFun_GPS_ZED-F9R_pHat.brd, SparkFun_GPS_ZED-F9R_pHat.sch]
2022-08-18 Updates silk, updates schmitt trigger package and symbol
    * Updates schematic layout
    [ZED-F9R_PhAT_v1.brd, ZED-F9R_PhAT_v1.sch]
2022-08-29 Updates F9R module, Fixes various trace overlaps and acid traps
    * Updates resistor values on LEDs
    * Adds more capacitance to power lines
    [ZED-F9R_PhAT_v1.brd, ZED-F9R_PhAT_v1.sch]
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

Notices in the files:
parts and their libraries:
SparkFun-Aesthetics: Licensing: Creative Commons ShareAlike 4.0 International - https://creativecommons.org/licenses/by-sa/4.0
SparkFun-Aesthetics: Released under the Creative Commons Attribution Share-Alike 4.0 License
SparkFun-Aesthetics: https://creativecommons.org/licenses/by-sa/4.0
